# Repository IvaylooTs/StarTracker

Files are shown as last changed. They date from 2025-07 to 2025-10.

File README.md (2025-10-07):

# Repo: Star Tracker

**Team Name:** CASSI  
**Project Name:** CASSI (Celestial Alignment System for Satellite Inertial-control)  
**Official Category:** Star Tracker 1

**Team Members:**  
Michael Yan, Ivaylo Tsekov, Alexandra Nedela, Dilyana Vasileva, Tsvetomir Staykov

## Note: for full and final documentation please read Star_Tracker_3.pdf
---

## Problem

How do we determine our attitude in space?

---

## Project Overview and End Goal

This project implements a star tracking system using a **Raspberry Pi** with an **AI camera** to determine the orientation of the system based on captured star images using a deterministic algorithm. Once calibrated, the system works in tandem with an IMU (Inertial Measurement Unit) to track orientation without continuous visual input. When drifting occurs, due to environmental variables, power loss, or other factors, the system automatically recalibrates.

---

## Current Available Demo

Go to the `digital_twin` folder in the `src` directory. It contains:

- `main.py` – main file with all the systems  
- `star_distances_sorted.db` – database with calculated angular distances, sorted in ascending order  
- `star_identified.png` – sample image from previous tests  
- `test_images` – dir with images from *Stellarium* for testing purposes (uses specific resolution and FOV)
- `create_hash.py` - a script to generate a hash map from database table "AngularDistances"
- `catalog_hash.py` - an already generated hash with the script above using 2 degree tolerance
- `stellarium360_new.js` - a script to be pasted into stellarium console for testing purposes
- `script_images` - dir with images generated from the above script

To run the script, you will need the `sqlite3` and `cv2` libraries installed on your system, and Python 3.

To run the script, use:
```bash
python3 main.py 
```

The results in your terminal should be:

- Indicator of which image you are currently processing
- Which mode you're in (Lost-in-Space / Tracking)
- The resulting quaternion from either of the two modes if one is produced
- The mapping of image star to HIP ID if one is produced

Files that should be generated when you run the script:

- For each image that you're processing you should get a file generated in this format "stars_identified_[index]"

---

## System Architecture

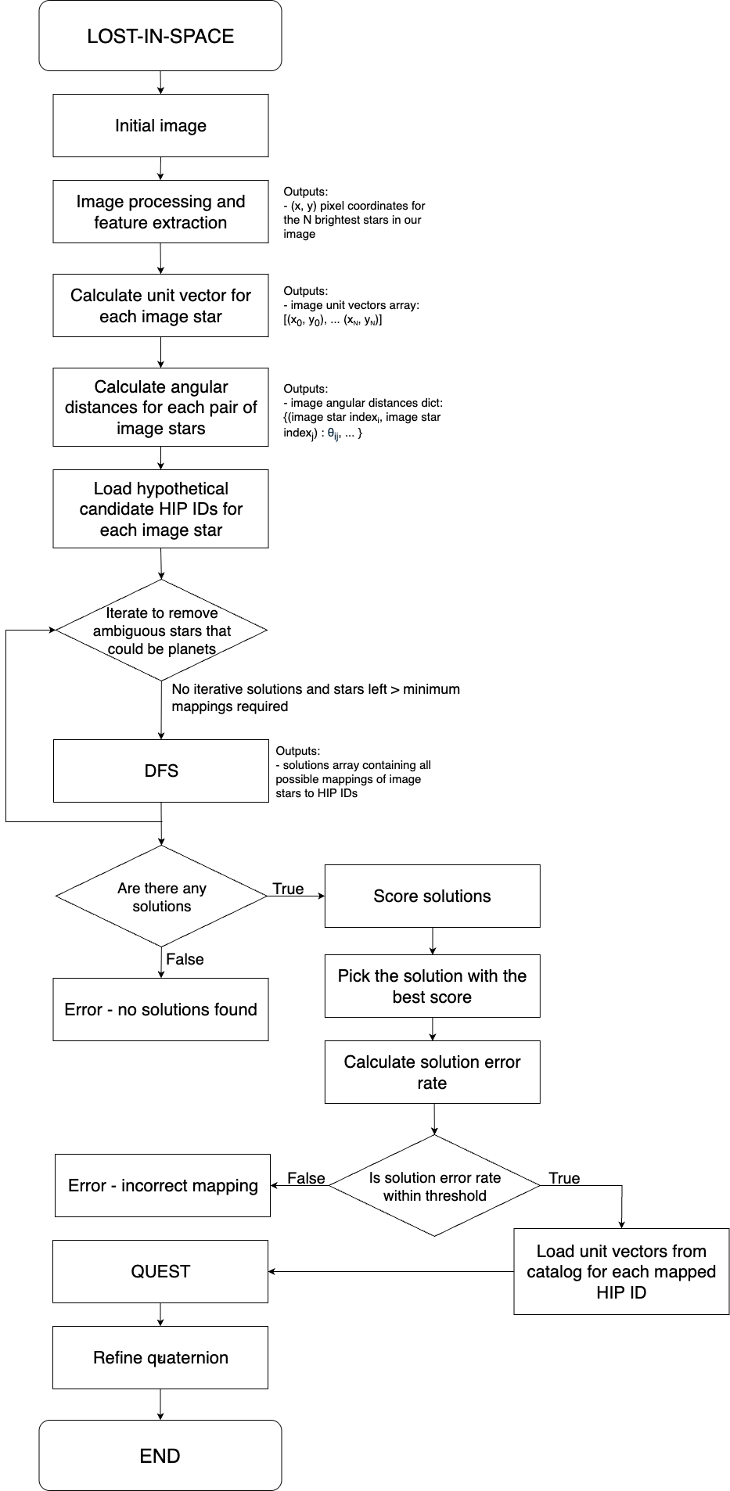
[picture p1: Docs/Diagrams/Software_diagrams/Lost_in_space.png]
Lost-in-Space algorithm Diagram


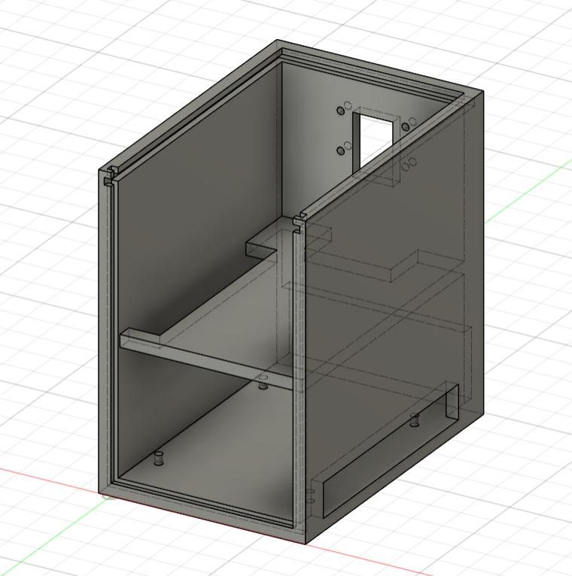
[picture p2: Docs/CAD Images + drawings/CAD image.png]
Cad Design


### Software

#### Database Structure

We have two tables in our database.  
**Table 1 – "Stars"** contains the HIP of each star according to the Hipparcos catalog, the magnitude of each star, and x, y, z coordinates of a unit vector corresponding to their RA and DEC coordinates in the equatorial coordinate system.  
**Table 2 – "AngularDistances"** contains the calculated angular distance between each pair of stars in Table 1, sorted from lowest to highest value.

The stars are filtered based on:

- Brightness  
- Size  
- Eccentricity

#### Lost-in-Space Algorithm

We're implementing a Lost-in-Space approach based on pair matching. The algorithm has four main parts:  
1. Image Processing and Feature Extraction  
2. Angular Distance Calculations  
3. Mapping to Catalog  
4. Attitude Determination

---

#### 1. Image Processing and Feature Extraction

The stars in the image are filtered based on: Brightness, Size, and Eccentricity.  
Then we select the N brightest stars in our image using blob detection and the `cv2` Python module. From this, we get the (x, y) coordinates of the center of each star in the image.

---

#### 2. Angular Distance Calculations

- We center the (x, y) coordinates of the stars based on our image's center, then convert them into vectors with the focal length as the coordinate along the z-axis  
- Convert them into unit vectors to reduce unnecessary computation  
- Calculate the angular distance between each pair (using the cosine of the dot product of the two vectors)

---

#### 3. Mapping Stars to Catalog 

- For each pair of stars in our image, we get the candidates ID pairs from our catalog hash
- Then we assign the candidate IDs for each image star based on a voting system
- Afterwards we run a DFS on this graph-like structure to find all possible mappings (even if incomplete)
- In the end we score the solutions we got from the DFS to get the best one

---

#### 4. Attitude Determination 

- From the final mapping of each star to a certain HIP in our database (from step above), we can now retrieve unit vectors from **Table 1**  
- We build the attitude profile matrix from the two sets of image and catalog vectors
- We then build the attitude profile matrix in quaternion form 
- We solve for the eigenvector with the largest eigenvalue which corresponds to our orientation quaternion

---

#### Tracking algorithm

- For tracking we use a previous orientation quaternion to predict where the stars in our previous image are going to be in the next one 
based on a certain amount of euclidian distance threshold this way we can make small and fast corrections to. We use the hungarian algorithm

---

### Hardware

#### Hardware Integration

- The initial orientation determined via camera is stored as a reference  
- The IMU is zeroed at this orientation  
- Subsequent orientation tracking is performed using only the IMU until recalibration is required due to drift

Notes and Ideas:
- A simple way to recalibrate would be to do it periodically  
- For improved accuracy, consider using Kalman filtering

---

#### Mechanical Design

- Modular, layered physical design:
  - Raspberry Pi  
  - IMU module  
  - Camera mounted perpendicular to the Raspberry Pi board  

- 3D CAD models and assembly diagrams are available in the `DOCS/` directory

---

##  Current Progress

### Software

- [x] Define project requirements  
- [x] Find algorithm for identification of stars  
- [x] OpenCV star identification on image  
  - [x] Test model with math on hand  
- [x] Get angular distances between stars  
- [x] Create database of parameters for comparison (star 1 HIP, star 2 HIP, angular distance)  
- [x] Select candidates for possible stars in specific locations  
- [x] Identify the correct stars  
- [x] Orientation in quaternion form
- [x] Testing  

### Hardware

- [x] Configure Raspberry Pi  
- [x] Connect required modules  
  - [x] Camera  
  - [x] IMU (Gyroscope, Accelerometer, Magnetometer)  
- [x] Calibrate IMU at hardware level  
  - [x] Measure drift  
  - [x] Research drift correction  
- [x] Calibrate IMU at software level  
- [x] Add interface for communication with Arduino (I2C is a good candidate)  
- [x] Develop firmware  
  - [x] Auto boot configuration  

### CAD

- [x] Construct simple box for fit testing and basic implementation  
- [x] Build a better box for testing and protection  
- [x] Satellite enclosure with removable modules  
  - [x] Bottom panel  
  - [x] Sliders  
  - [x] Test sliders  
  - [x] Side protection panels  
  - [x] CASSI module  

### Additional

- [x] Testing | Make black box for testing using images on a monitor  
- [x] Visualization | Make control panel  
  - [x] 3D visualization  
  - [x] Live video  
  - [x] OpenCV calculations  
  - [x] Control buttons  
- [x] Check if static IP is needed (just in case)  
- [x] Study commercial star tracker manuals  
- [x] Consider handling edge cases such as solar flares, moonlight, sun/earth stray light, etc.

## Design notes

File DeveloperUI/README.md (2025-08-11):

# Cassi Developer Interface

Control different aspects of the Cassi system. Visualize data and check if everything is correct.

#### Current windows:
 - 3D visualization of the quaternions
  - toggleable vectors and objects
 - graph for checking for errors in quaternions.
 - buttons with macro commands for fast execution on important commands - lost in space, calibrate, add offset, compare offsets, shutdown, reboot
 - console for CLI interface and live data transfer
 - camera overview
 - simple display information - current quaternion, temp, ram, cpu usage

#### How to run:
Activate `python3 start.py` to boot into server. Originally we wanted to not use server, but due to Cross-Origin Request problems, simplest solution was to boot python server.

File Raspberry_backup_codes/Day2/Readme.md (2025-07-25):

## Day 2 

- Camera connection
- Live video display

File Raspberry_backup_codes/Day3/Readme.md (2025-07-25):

# Day 3

- IMU connection
- Display data in server

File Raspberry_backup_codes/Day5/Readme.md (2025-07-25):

## Day 5

- Calibration with magnetic recalibration stopped
- Recalibration via file on activation

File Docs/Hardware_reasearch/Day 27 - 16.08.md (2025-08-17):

- Make architecture for raspberry pi to change modes
- Make final draft of the documents for hardware and firmware
- make graphs
- study (optinal)

- add button for ui to open image in full screen

We did testing and Ivo made the wrap of lost in space to run many tests on his machine. 
I thought there were problems with the quaternions, but just problem on my laptop visualization was broken, on Ivo's computer it worked without any problems, providing amazing images. Then he coded error determination based on Michael's instructions and we got amazing view of the statistics and tracked average time for 155 images.

Currently Ivo is running around 150 images with different star counts (from 10 to 30), to find the best values for the system. We tried multi-threading, but found problems with the resources being unevenly divided and this show problems with the timing process. Better approach will be, sum operations or single threaded operation for accurate run, then compare the results.

We designed few other tables for the documentation and expanded the hardware and software architecture.

We designed the test with crosses on the screen to align the camera more correctly and get better results. This provided faster calibration on top of the stand.

Tests from Ivo's:
![[Figure_1(1).png]]

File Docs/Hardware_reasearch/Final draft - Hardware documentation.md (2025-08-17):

### Introduction
Introduction to terminology:
- Main board - Small computer, in our case Raspberry PI 4, 4Gb
- IMU - Inertial Measurement Unit, in our case Bosch BNO055
- Camera - in our case SONY IMX500

The hardware system of the star tracker is designed for headless operation in setups:
 - satellite integrated - no outside interfaces, just two-directional communication to another subsystem. 
 - workstation development environment - connected to WiFi, allowing access to development interface, data visualizations and command line interfaces (via the developer interface or secure shell).

If more information is required, please check out the [BNO055 datasheet](https://cdn-shop.adafruit.com/datasheets/BST_BNO055_DS000_12.pdf) by Bosch.
Sadly we couldn't obtain access to the [IMX500 datasheet](https://developer.sony.com/imx500/developer-tools/specifications/reference-and-specifications-archive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) by Sony. For more information contact them.
#### Hardware Specifications and main components List
The system is comprised of 3 main components. Camera, IMU and small main board computer.
##### Camera
- based on Sony IMX500 Intelligent Vision Sensor
	- Why is good: Big pixel count, fast operation and small form factor.
	- Problems: Big field of view, Manual focus (not motorized) 

| Specification | Details |
| --- | --- |
| Sensor | Sony IMX500 |
| Resolution | 12.3 megapixels |
| Sensor size | 7.857 mm (type 1/2.3) |
| Pixel size | 1.55 μm × 1.55 μm |
| Horizontal/vertical | 4056 × 3040 pixels |
| IR cut filter | Integrated |
| Autofocus system | Manual adjustable focus |
| Focus range | 20 cm – ∞ |
| Focal length | 4.74 mm |
| Horizontal field of view | 66.3 ±3 degrees |
| Vertical field of view | 52.3 ±3 degrees |
| Focal ratio (F-stop) | F1.79 |
| Infrared sensitive | No |
| Output | Image (Bayer RAW10), ISP output (YUV/RGB), ROI, metadata |
| Dimensions | 25 × 24 × 11.9 mm |
| Cable connector | 15 × 1 mm FPC or 22 × 0.5 mm FPC |
| Rated operating temperature | 0°C to 50°C |
##### IMU 
- based on BOSCH BNO055 Sensor. 
	- Why is good: Fast operation, simple interface, 9 axis, accurate.
	- Problems: closed algorithms

###### General

| Feature | Details |
| --- | --- |
| Outputs | Quaternion, Euler angles, Rotation vector, Linear acceleration, Gravity, Heading |
| Sensors | 16-bit triaxial gyroscope, 14-bit triaxial accelerometer, full-performance geomagnetic sensor |
| Package | LGA, 28 pins; Footprint: 3.8 × 5.2 mm²; Height: 1.13 mm² |
| Power Management | Intelligent Power Management: normal, low power, suspend modes |
| Voltage Supply | VDD: 2.4–3.6V; VDDIO: 1.7–3.6V |
| Digital Interface | I²C, UART |
| Compliance | MSL1, RoHS compliant, halogen-free |
| Operating Temperature | -40°C … +85°C |
###### Accelerometer

| Feature | Details |
| --- | --- |
| Acceleration Ranges | ±2g, ±4g, ±8g, ±16g |
| Low-Pass Filter Bandwidth | 1kHz – <8Hz |
| Operation Modes | Normal, Suspend, Low power, Standby, Deep suspend |
| On-chip Interrupts | Any-motion (slope), slow/no motion recognition, high-g detection |
###### Gyroscope

| Feature | Details |
| --- | --- |
| Ranges | ±125°/s – ±2000°/s |
| Low-Pass Filter Bandwidth | 523Hz – 12Hz |
| Operation Modes | Normal, Fast power up, Deep suspend, Suspend, Advanced power save |
| On-chip Interrupts | Any-motion (slope), high rate |
###### Magnetometer

| Feature | Details |
| --- | --- |
| Magnetic Field Range | ±1300μT (x-, y-axis), ±2500μT (z-axis) |
| Magnetic Field Resolution | ~0.3μT |
| Operating Modes | Low power, Regular, Enhanced regular, High Accuracy |
| Power Modes | Normal, Sleep, Suspend, Force |
###### Main board
- Raspberry PI 4
	- Why is good: Enough computational power, low energy consumption, many interfaces, many libraries and different ways to integrate.
	- Problems: Closed firmware. Too many unused features.
	
| Feature | Specification |
| --- | --- |
| Processor | Broadcom BCM2711, quad-core Cortex-A72 (ARM v8) 64-bit SoC @ 1.8GHz |
| Memory | 4GB LPDDR4 with on-die ECC |
| Connectivity | • 2.4 GHz and 5.0 GHz IEEE 802.11b/g/n/ac wireless LAN<br>• Bluetooth 5.0, BLE<br>• Gigabit Ethernet<br>• 2 × USB 3.0 ports<br>• 2 × USB 2.0 ports |
| GPIO | Standard 40-pin GPIO header (fully backwards-compatible with previous boards) |
| Video & Sound | • 2 × micro HDMI ports (up to 4Kp60 supported)<br>• 2-lane MIPI DSI display port<br>• 2-lane MIPI CSI camera port<br>• 4-pole stereo audio and composite video port |
| Multimedia | H.265 (4Kp60 decode); H.264 (1080p60 decode, 1080p30 encode); OpenGL ES 3.0 graphics |
| SD Card Support | Micro SD card slot for loading operating system and data storage |
| Input Power | • 5V DC via USB-C connector (minimum 3A)<br>• 5V DC via GPIO header (minimum 3A)<br>• Power over Ethernet (PoE)–enabled (requires separate PoE HAT) |
| Environment | Operating temperature: 0–50ºC |
| MTBF | Ground Benign: 211,000 hours |

#### Environmental Specifications

#### Connectors / Pinouts

The product has Female Header (0.1-inch / 2.54 mm pitch) for connection with other subsystems and giving power to the device. The communication pins allow full-duplex UART communication . The power pins allow to power the device with +5 volts direct current.

![[Pasted image 20250815011902.png]]
Even though the main computer of the system has many connections, only few of them are used.

| Pin name | alternative name | pin number | Used for |
| --- | --- | --- | --- |
| 3v3 | | 1 | powering the IMU |
| GPIO2 | I2C SDA | 3 | IMU data communication  |
| GPIO3 | I2C SCL | 5 | IMU clock sync |
| GPIO14 | UART TX | 8 | Subsystem UART transmit |
| GPIO15 | UART RX | 10 | Subsystem UART receive  |
| GND | | 9 | gounding to IMU |

The Camera is connected directly to the Camera Serial Interface connector, via flat ribbon cable.

![[New Project(2).png]]

The current version uses perfboard (Stripboard or Veroboard) with connections on the bottom (similar to raspberry pi hats), allowing for easy assembly and better connection.

 [picture here]

### Power consumption
#### 

#### Interface Descriptions
- The IMU communicated with the main board via Inter-Integrated Circuit (I2C) communication, which allows for simple 2 wire interface.
- The camera communicated via MIPI (Mobile Industry Processor Interface) Camera Serial Interface standard, which allows high-bandwidth and low-latency data transfer.
- Other subsystems communicated via Full-duplex UART communication, which allows two directions communication at the same time. This interface can be expanded with the cubesat space protocl, like [libscp](https://github.com/libcsp/libcsp). 
  
  ==**!!! Important !!!** The communication protocol uses 3.3 volts due to requirements of the board and the specifications of the General Purpose Input/Output pins, even though the board is powered from 5 volts.
  
- Wifi is used to communicate with the developer interface and the secure shell protocol. This allows for updates, setup of the system and changes in the source code.
#### Firmware

###### Operating system
The operating system of the device is minimalist version of Linux Debian, made specifically for raspberry pi - **Raspberry Pi OS Lite 32-bit**. It runs in **headless** mode with minimal software and drivers, it provides good embedded environment for experimentation with simple integration and possibility for expansion.

| Specification | Data |
| --- | --- |
| Operating system version | Debian version 12 (Bookworm) |
| Firmware version | 24.10.0 |
| Operating system bit | 32-bits |
| Size | 493 MB |
| Kernel version | 6.12 |
###### System architecture
The code is written on python with many modules design for specific purpose:
- main - Combines all modules, runs specific parts in threads, cleans up after execution
- logger - Saves logs, displays information, displays logo, headers, organized output
- math - Computations and arithmetic functions
- flask_server - https server for live video feed and picture download (used for developer interface)
- web_sockets - tcp connection for command and live information transfer (used for developer interface)
- lost_in_space - main algorithms for calculating the attitude based on camera information.
- image_processing - support algorithms for lost_in_space. Identifying stars, etc.
- database and hashmap - all needed values for computation of the algorithms

###### External Device Compatibility
We need to consider that the connection with other subsystems require additional the voltage to be around 3.3 volts. The reason is the operational voltage of the main computer in the device. If you want to operate outside the scope of this, you risk to damage the internal computer.
###### Boot cycle efficiency and optimizations
specific settings were set into place to ensure faster load time of the system.
This are the current settings of the `/tmp/firmware/config.txt`:
```bash
disable_splash=1
boot_delay=0
initial_turbo=30
dtparam=audio=off
dtparam=spi=off
display_auto_detect=0
```

There is problem, where the allocation of less than 32 Mb of memory for the graphical processing unit, don't allow the camera to initialize correctly.   
```
gpu_mem=16
```
For now we will leave it at default value of 128 Mb to ensure stability.
This didn't impact the boot time.

the most improvement in boot speed came from
```bash
sudo systemctl disable NetworkManager-wait-online.service 
```
This cut the boot time with 50%. 

other services were removed to make the device faster and remove unnecessary scripts and programs running in the background
```
bluetooth
hciuart
avahi-daemon
triggerhappy
rpi-eeprom-update 
keyboard-setup
```
Attempts to optimize the SD card, where the whole firmware was stored, were unsuccessful
```
(example)
dtparam=sd_overclock=100 - didn't work, not used
```
after this optimizations we only got down with just 8% 

At the end, we got from around 11 seconds boot time to 5.5 seconds. Which is in the range of most cubesats boot time - around 10-60 seconds.
The shutdown time is around 3-4 seconds, which grants us around 15 second reboot time (some delays present) for the operating system.

The IMU has start-up time from off to configuration mode in 400 milliseconds typical time. and from reset to normal mode in 650 milliseconds mode.
###### System boot sequence
![[BootCycle.drawio(2).png]]

After the system boots, linux service is started. The service is designed to reboot in case of crash of the program it represents - in this case a bash script that reloads the main program.
The bash script is used to ensure that the main program can reboot and call different exit conditions from the developers. The service is to allow overview of the process and to ensure initialization of the boot script and its recovery.

The main program kills every thread that uses port 5000 and 6789, to free slots for Flask server and Websocket. Then the main program runs. There are few cases to consider:
- Exit code 2 - reboots the whole system
- Exit code 3 - shutdowns the whole system
- Any other exit code - reboot program. We use 23 to represent reboot called from the developer interface.
- Crash of main program - reboot program
- Crash of bash boot script - Service reloads

#### Logger
Small script is used to record data with custom commands. We save everything in `logs/` folder, where each file is timestamped.  Custom commands are made for displaying information in the terminal and the file.
Format is "Time | Message type | Information"
Message types are:
- Info
- Success
- Warning
- Error
- Fatal error

## operation
flow charts
systems
architecture
data handling
whatever there is

###### Power consumption

The main board on the system is rated for direct current from power supply, which can deliver 3 amps at 5 volts. The documentation of the device rates typical bare-board active current consumption at 600 milliamps. The GPIO pins can deliver 3.3v at max 16 milliamps current.

| step/process | Amps drawn (A) |
| --- | --- |
| Booting - max | 0.85 |
| Booting - avg. | 0.7 |
| Booting - min | 0.6 |
| Stress -  max | 1.25 |
| Stress - average | 1.2 |
| Halt current (shutdown state) | 0.023 |

Note: These measurements used a standard Raspberry Pi OS image (current as of 26 Feb 2016, or June 2019 for the Raspberry Pi 4), at room temperature, with the Raspberry Pi connected to a HDMI monitor, USB keyboard, and USB mouse, connected to Ethernet. Power consumption can easily exceed these measurements if multiple additional USB devices or a HAT are connected to the Raspberry Pi.

The IMU runs from 2.4V to 3.6V. Total supply current in normal mode with 9 degrees of freedom at 100 Hz output data rate is 12.3 milliamps. The IMU can run in few modes that can save power ( like "Low power" ). We currently only work with normal operation with stopped fast calibration of the magnetometer. 

Possible upgrades:
- Possible extensions on the system to detect current drop below 4.63V (±5%) can be added in the future.

#### Single event upsets (SEU)
In **Low Earth Orbit (LEO)**: SEFIs are expected about **once every ~100 days** per Pi (worst case). Actual rates may be 2–3× lower. 
There is no built-in hardware mitigation. Because Raspberry PIs are designed for commercial on ground off-the-shelf deployment. They don't have any hardware integrations for error-correcting memory or hardened logic. This single event upsets can flip specific sectors, break calculations or even crash the system. There is no **Error-Correcting Code (ECC)** memory on the chip. 

Possible problem can be:
- **bit errors:** crashes, corrupted variables, loops running out of bounds. 
- **Single event function interupts:** Linux kernel panics, system lockups, or garbage communication output. 
- **Permanent failures:** rare but possible from latchups or SD card corruption

Some software implementations can be introduced on the system, but they are not as reliable as hardware that is specifically space-graded. For this version we use most of the default configuration of the operating system, so many things like watch dogs are not activated.

Possible upgrades:
- Install protection mechanisms:
	- Automatic power-cycling if error is detected
	- Change SD card with more redundant/space-graded technology
	- External ECC memory modules
	- filesystems like **Btrfs** or **ZFS** to detect corruption and/or other application level checksum
	- hardware watchdogs timers (Raspberry pi have software watch dogs, but separate modules are mandatory for secure operation)
	- Structural shielding from particles

### IMU Settings
We run the IMU in **NDOF_FMC_OFF** to stop recalibration after booting and loosing general direction. This allows us to not lose direction in case of rebooting the software ran on the star tracker. We stopped the heading calibration and load custom calibration from file. The system is designed for LEO missions, so the magnetometer can be used for calibration of the system. Here few design choices come into play when deciding if magnetometer recalibration on boot is required. In our case we choose to not do it and allow the lost in space algorithm to run the recalibration. This can be changed in future versions or depending on customer requirements.

The IMU settings allow for change in the axis mapping. This is done with a register *AXIS_MAP_CONFIG* and can help when the IMU is not places directly toward the camera. After that we do 45 degree offset to align it with the camera, software wise.

In our NDOF_FMC_OFF mode we allow for the outputs rates of:

| Accel  | Mag | Gyro | Fusion data |
| --- | ----- | --- | --- |
| 100 Hz | 20 Hz | 100 Hz | 100 Hz |

When booting in normal operation mode, by default we load this standard configuration mode

| Sensor | Parameter | Value |
| --- | --- | --- |
| Accelerometer | Power Mode | NORMAL |
| | Range | ±4g |
| | Bandwidth | 62.5 Hz |
| | Resolution | 14 bits |
| Gyroscope | Power Mode | NORMAL |
| | Range | 2000 °/s |
| | Bandwidth | 32 Hz |
| | Resolution | 16 bits |
| Magnetometer  | Power Mode | FORCED |
| | ODR | 20 Hz |
| | XY Repetition | 15 |
| | Z Repetition | 16 |
| | Resolution x/y/z | 13/13/15 bits |
Some of this values are not controllable directly from the developer, but are changed based on the fusion mode used in the chip.

### ** Installation & Setup**
==Most of this should be expanded, because in current state we haven't prepared shipping and packaging. Current development may change the form factor. This is general overview for future documentation== 
#### Unboxing Instructions
The packaging materials are not ready, but this is the planed system:

Open the box you received. Remove the top packing material. Carefully take the Star tracker out of the box. In the box you will also find additional manuals, wires, connector, adapters, testing stand, spare bolts, cleaning materials, stickers, etc..
No special protection or equipment is needed if you want to use it in desk mode, to learn and experiment. 

##### Protective covers
The star tracker relies on camera that need to be clean and ready to take picture at any time. For this reason the device comes with protective cap on top of the camera. Its purpose is to stop dust, humidity or any outside particles and environment variables to interact and lower the efficiency of the star tracker. Remove this cap for testing and before flight. Remember to clean the camera with the provided cleaning materials and/or according to the instructions.

**Cleaning the Star Tracker**

1. **Power Off:** Make sure the device is turned off and unplugged from all power sources.
2. **Dust Removal:** Use a can of clean, dry compressed air to blow away any dust from the lens, connectors, and vents. Hold the can upright and spray in short bursts to avoid condensation.
3. **Lens Cleaning:**
    - If there are smudges on the lens, use a lens cleaning pen or a microfiber cloth made for camera optics.
    - Do not press hard — wipe gently in a circular motion.
    - If needed, add a drop of optical lens cleaning solution to the cloth (never directly on the lens).
4. **Body Cleaning:** Wipe the housing with a soft, dry cloth. Slightly damp cloths are fine for stubborn marks. Never let liquid enter any opening. 

**Protective Covers**
- **Lens Cap:** Always put the supplied lens cap on when the Star Tracker is not in use. This prevents dust, scratches, and accidental fingerprints.
- **Connector Covers:** If your model includes rubber or plastic covers for USB-C, UART, or power connectors, place them after each use to keep out dust and debris.
- **Transport Case:** For storage or transport, place the Star Tracker back into its original foam-lined box or into a padded protective case to protect against shock and vibration.
**Important:**
- Never use household cleaning sprays, alcohol, or abrasive materials on the lens or housing.
- Avoid storing the unit in direct sunlight, humid areas, or near strong magnetic/electrical fields.
#### Physical Installation / Mounting Instructions
The star tracker is design to install in CubeSat with sizes of 1U to 3U, or any system that can support the design [please expands]. The system also can be installed on desk or workstation, connected via usb-c for power.
All bolts in the design are m2 screws with specific length and star head end, coutner sunk or some shit, idk, Michael your turn
#### Electrical Connections
The raspberry pi can be connected via usb-c for desk/workstation operation 
When you need to install the system in the satellite, connect the UART and power pins based on the provided diagram.

##### Initial Power-Up Procedure
Power the device with the power requirements described in section [somewhere]

Before powering the device make sure all connection are secure and there is no visible damage on the device. Ensure Ethernet cable is connected so that you can connect to via secure shell or the developer interface and control the software. 
When the device received power, the booting process starts.
On first boot it enters into standard desk operation. In this way you can connect to it and change the system parameters.

Future upgrades:
- make pin for selecting the operational based if it connected to ground or not

##### Configuration and Calibration
The device comes with small white circle with small pins to calibrate the focus of the camera. The current setup requires to use external monitor for testing (16:9 aspect ration), positioning the camera module to be able to capture the whole monitor. After positioning you can rotate the camera lens, by positioning the calibration tool on top of the camera lens, by aligning the hole in the middle. Look at the developer software to see the change of focus. In this way you can find the optimal focus length for your test bench. The provided stand is for 23 inch monitor with 16:9 aspect ratio.
You can test the functionality from the command line interface or the buttons provided. The secure shell connection doesn't allow for command to be send when we are in ssh session with booted and displayed Star Tracker Software. In that case you control the system via the Developer interface. The ssh is used for direct control and access of the source code.

Future upgrades:
- Stand with ability to manually change position, based on the size of screen.
- Better secure shell CLI interfacing for direct control without the GUI.
### **Maintenance & Troubleshooting**
- Routine Maintenance Guidelines
- Troubleshooting Guide (symptoms → causes → fixes)
### Firmware Update Procedure
if you want to update the firmware you can download and flash an iso by contacting customer support from the link on our website or download the source code from Github and install it manually on the device via the scp.
https://github.com/IvaylooTs/StarTracker
Note: Save your settings by exporting them manually. You can easily override them and lose valuable configuration settings. 

Future upgrade:
- Simple export and import for settings via the developer interface and ssh
#### Replacement Parts / Consumables
The raspberry pi 4Gb, sd card, AI camera and IMU can be found from many distributors and this makes the current version of the system - accessible and easily reparable. For the pcb design, structure or any other part, contact us via our customer email or our website.   

## Developer Interface
The developer interface is designed specifically to run on computer, connected on the same network as the main computer. It provides overview and visualization of the most important information. It is programmed with html, css and javascript like a normal website. Libraries used are Three.js for 3d visual visualization and Graph.js for quaternion data visualization in graphs

It connects via websocket on port 6789 to transmit data in two directional. The data is transfer in json format. The main board sends constantly data about its quaternion rotation, temperature, cpu and ram loads. Any other information is manually requested with command in the command line interface (or just console) inside the developer interface. Few command can be send via buttons for faster call:
- save and download current video feed image as picture on the user computer
- activate test with image on board
- activate lost in space with camera view
- add custom quaternion value
- calibrate IMU to last calibration
On the left of the terminal is present live data feed and on the right are last command and acknowledgements made from the raspberry pi and the system.
If connection is lost or not made, websocket tries to reconnect. Some problem are recorded that it can take some time to establish connection. It can range between instant connection to 10-15 seconds wait. Refreshing the interface, rebooting the software or cleaning the cached page data seem to help for now. (this will be fixed in future developments)

Flask server is loaded with live feed from the camera. It can be accessed on port 5000 from any browser in with URL "https://{ip}:5000/video_feed". It is also displayed in small window in the developer interface. We use https, because of cross site resource management and display. The problem occurs, because the video feed is hosted on the raspberry pi and the visualization happens on our web interface on another computer. We use locally generated certifications and we need to connect to the link above to accept "the risks" with connecting to this system.

Note: The Websocket and Flask server are not active in Satellite mode.

Initial concept design:
![[ConceptUI.drawio.png]]

Current version:
![[Pasted image 20250816112906.png]]

Most of the things are the same as the concept. We can see that the the graph and system data visualization are switched. on the panel on the right you can scroll down to see more control buttons for testing (in controls panel), and system stats (in the visualized data).

Console visualized:
![[Pasted image 20250816113234.png]]

Camera window:
![[Pasted image 20250816113339.png]]

Visualization toggle:
![[Pasted image 20250816113548.png]]

Note: The star visualization on the 3D visualization is only visible when the python script 'start.py' is started and we are connected to the local ip. We cannot load the image the image because of some html problems and resource management.

Future upgrades:
- more control buttons
- better visualization
- movable windwos
- more graphs and information

### On board CLI
When you boot into the raspberry pi and run the script manually, you see this visualization 
![[Pasted image 20250816114728.png]]
![[Pasted image 20250816114743.png]]![[Pasted image 20250816114829.png]]
This helps you display debugging information

The problem is that you cannot write CLI commands while you are in this interface.
For future development we can add this function.

### **Testing & Validation of hardware**

- Factory Test Procedures
- Quality Control Checklist
- Environmental Stress Tests
- Electrical and Functional Testing
### **Diagrams & Schematics**

- Block Diagrams
- Circuit Schematics

- PCB Layouts

- Wiring Diagrams

## Developer interface

### **Appendices**

- Glossary of Terms
- Reference Documents / Standards
- Revision History / Changelog
- Contact Information / Support

https://randomnerdtutorials.com/raspberry-pi-pinout-gpios/

https://www.raspberrypi.com/documentation/computers/raspberry-pi.html#power-supply
https://nepp.nasa.gov/docs/papers/2021-Guertin-Raspberry-Pi-Guideline-CL-21-5641.pdf

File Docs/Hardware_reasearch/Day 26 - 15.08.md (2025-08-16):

- System architecture for boot and picture capture
- UART comms
- softwar

Build Sat/Desk mode change, Decided on architecture for downloading data
![[Pasted image 20250816101217.png]]

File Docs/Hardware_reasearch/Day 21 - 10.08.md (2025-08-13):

- [ ] Fix the UI 
	- [x] Quaternions
		- [x] Add a way to toggle the displayed values
		- [x] Angles difference
	- [ ] Additional
		- [ ] Fix the button sizes
		- [ ] Connect the reboot and shutdown button
- [x] Check the quaternions from the calibration
	- [x] Check if rotation is fine in pitch and yaw
	- [ ] Check the Roll
- [ ] Integrated precise measurements
	- [x] Check if Didi's code is actually working with low tolerance
	- [x] Check if my code works on Didi's resolution
- [x] Integrate the box
	- [x] Tell Michael to build a test rig holder
- [ ] Fix the integration interface
	- [ ] Add base interface for command calls
- [x] Study for the test
	- [x] Lectures
		- [x] Remote sensing
		- [x] 3D mechanical design
		- [x] Git
- [ ] if enough time
	- [ ] movable windows for camera

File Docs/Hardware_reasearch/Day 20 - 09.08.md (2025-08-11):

- [ ] Fix the UI 
	- [x] CLI comms
		- [x] Integrate the CLI inside the browser
		- [x] Seperate the data into Data-link and Commands
		- [x] Fix the acknowledgement for the CLI interface
	- [ ] Quaternions
		- [x] Do a better visualization of the calibrated quaternions
		- [ ] Add a way to toggle the displayed values
		- [x] Orbital controls
		- [ ] Angles difference
	- [ ] Additional
		- [ ] Fix the button sizes
		- [ ] Connect the reboot and shutdown button
- [ ] Check the quaternions from the calibration
	- [ ] Check if rotation is fine in pitch and yaw
	- [ ] Check the Roll
- [ ] Integrated precise measurements
	- [ ] Check if Didi's code is actually working with low tolerance
	- [ ] Check if my code works on Didi's resolution
- [ ] Integrate the box
	- [ ] Tell Michael to build a test rig holder
- [ ] Fix the integration interface
	- [ ] Add base interface for command calls
- [x] Study for the test
	- [x] Check if there are any videos on spaceport
	- [ ] Lectures
		- [x] How to make a star
		- [x] Quantum
		- [x] To space / through space
		- [x] the urgent need for solutions and the policy
		- [ ] Remote sensing
		- [ ] 3D mechanical design
		- [ ] Git
- [ ] if enough time
	- [ ] movable windows for camera

Added visualization on the UI so the focus is on the 3D view. Made camera and CLI toggleable in the down left corner of the screen. Want to add so you can move the window, but that is not necessary right now Added console inputs so i can send custom commands to the raspberry, even ones that are not in the buttons.
Make the received data into one window and commands in the other. Made functions to write to them separately.

Now I need to add last quaternion calibration. I tried doing it saving it on the html, but decided to move it on the raspberry pi for simpler execution and send the data via command.

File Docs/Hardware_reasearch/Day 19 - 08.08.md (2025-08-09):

after the hike i tried to implement the the "Nuke" solution into the main digital_twin code, sadly no luck. 
Experiments show that the error in the angular distances are the same as the "Nuke" fix for few selected stars. Need to check with Didi for that. 

The uart protocol is implemented by Ivo. We think of 2 interfaces - websocket and uart. They are on top of one singular interface, that has all the commands that the raspberry can implement. 

```python
import numpy as np

# Original quaternions given
q1 = np.array([-0.05475243,  0.00503133,  0.00334414,  0.99848168])
q2 = np.array([0.53389495, -0.26937958, -0.25995519, -0.75816498])

def normalize(q):
    return q / np.linalg.norm(q)

def angle_between_quaternions(q1, q2):
    q1 = normalize(q1)
    q2 = normalize(q2)
    dot = np.abs(np.dot(q1, q2))
    dot = np.clip(dot, -1.0, 1.0)  # Clamp for safe arccos
    angle = 2 * np.arccos(dot)
    return np.degrees(angle)

# 1) (x, y, z, w) ordering
angle_xyzw = angle_between_quaternions(q1, q2)

# 2) (w, x, y, z) ordering: rearrange components
q1_wxyz = np.array([q1[3], q1[0], q1[1], q1[2]])
q2_wxyz = np.array([q2[3], q2[0], q2[1], q2[2]])
angle_wxyz = angle_between_quaternions(q1_wxyz, q2_wxyz)

angle_xyzw, angle_wxyz

```

```javascript
// capella_label_and_coords.js
// Move to Capella, print coordinates, and add a dark-gray label "capela test 1"

// Helper: convert RA in decimal degrees to "HH:MM:SS.s"
function raDegToHMS(raDeg) {
    // RA: 360 deg = 24h -> hours = raDeg / 15
    var totalHours = raDeg / 15.0;
    var H = Math.floor(totalHours);
    var mFrac = (totalHours - H) * 60.0;
    var M = Math.floor(mFrac);
    var s = (mFrac - M) * 60.0;
    // format with fixed seconds to 2 decimals
    return H + ":" + (M < 10 ? "0"+M : M) + ":" + s.toFixed(2);
}

// Helper: convert Dec in decimal degrees to "±DD:MM:SS.s"
function decDegToDMS(decDeg) {
    var sign = decDeg < 0 ? "-" : "+";
    var absDec = Math.abs(decDeg);
    var D = Math.floor(absDec);
    var mFrac = (absDec - D) * 60.0;
    var M = Math.floor(mFrac);
    var s = (mFrac - M) * 60.0;
    return sign + D + ":" + (M < 10 ? "0"+M : M) + ":" + s.toFixed(2);
}

try {
    // 1) Select object and move view to it
    core.selectObjectByName("Capella", true);      // select (pointer on)
    core.moveToObject("Capella", 1.0);             // move view to Capella in 1 second

    // short wait to ensure selection/move are done in the script (adjust if needed)
    core.wait(1.0);

    // 2) Obtain object info map
    var info = core.getObjectInfo("Capella");

    // 3) Safely read RA/Dec (current frame) and J2000 if available
    var raDeg = (typeof info["ra"] !== "undefined") ? info["ra"] : null;
    var decDeg = (typeof info["dec"] !== "undefined") ? info["dec"] : null;
    var raJ2000 = (typeof info["raJ2000"] !== "undefined") ? info["raJ2000"] : null;
    var decJ2000 = (typeof info["decJ2000"] !== "undefined") ? info["decJ2000"] : null;

    // 4) Print full info map for debug / completeness
    core.output("---- Capella: raw info map ----");
    core.output(core.mapToString(info));
    core.output("--------------------------------");

    // 5) Print nicely formatted coordinates
    if (raDeg !== null && decDeg !== null) {
        core.output("Current-frame RA  (deg): " + raDeg.toFixed(6));
        core.output("Current-frame Dec (deg): " + decDeg.toFixed(6));
        core.output("Current-frame RA  (HMS): " + raDegToHMS(raDeg));
        core.output("Current-frame Dec (DMS): " + decDegToDMS(decDeg));
    } else {
        core.output("Current-frame RA/Dec not available in getObjectInfo() result.");
    }

    if (raJ2000 !== null && decJ2000 !== null) {
        core.output("J2000 RA  (deg): " + raJ2000.toFixed(6));
        core.output("J2000 Dec (deg): " + decJ2000.toFixed(6));
        core.output("J2000 RA  (HMS): " + raDegToHMS(raJ2000));
        core.output("J2000 Dec (DMS): " + decDegToDMS(decJ2000));
    } else {
        core.output("J2000 RA/Dec not present in the info map (some Stellarium versions may omit them).");
    }

    // 6) Add a dark-gray label attached to the object.
    // Parameters: text, objectName, visible, fontSize, fontColor, side, labelDistance, style
    // Use a dark gray color like "#444444"
    var labelId = LabelMgr.labelObject("capela test 1", "Capella", true, 14, "#444444", "E", -1.0, "TextOnly");

    if (labelId >= 0) {
        core.output("Label created (id = " + labelId + "). Text: \"capela test 1\" Color: #444444");
    } else {
        core.output("Failed to create label. Ensure the object name 'Capella' is available in English in this Stellarium instance.");
    }

} catch (e) {
    core.output("Script error: " + e.toString());
}

```

```javascript
// polaris_label_and_coords.js
// Removes previous Capella label, moves to Polaris, prints coordinates, adds label "polaris test 1"

// Keep the label ID from previous script if in same Stellarium session
try {
    if (typeof labelId !== "undefined" && labelId >= 0) {
        LabelMgr.deleteLabel(labelId);
        core.output("Removed Capella label (id = " + labelId + ").");
    } else {
        core.output("No previous Capella label found to remove.");
    }
} catch (e) {
    core.output("Error while removing Capella label: " + e.toString());
}

// Helper: convert RA in decimal degrees to "HH:MM:SS.s"
function raDegToHMS(raDeg) {
    var totalHours = raDeg / 15.0;
    var H = Math.floor(totalHours);
    var mFrac = (totalHours - H) * 60.0;
    var M = Math.floor(mFrac);
    var s = (mFrac - M) * 60.0;
    return H + ":" + (M < 10 ? "0"+M : M) + ":" + s.toFixed(2);
}

// Helper: convert Dec in decimal degrees to "±DD:MM:SS.s"
function decDegToDMS(decDeg) {
    var sign = decDeg < 0 ? "-" : "+";
    var absDec = Math.abs(decDeg);
    var D = Math.floor(absDec);
    var mFrac = (absDec - D) * 60.0;
    var M = Math.floor(mFrac);
    var s = (mFrac - M) * 60.0;
    return sign + D + ":" + (M < 10 ? "0"+M : M) + ":" + s.toFixed(2);
}

try {
    // 1) Select object and move view to it
    core.selectObjectByName("Polaris", true);
    core.moveToObject("Polaris", 1.0);

    // short wait
    core.wait(1.0);

    // 2) Obtain object info
    var info = core.getObjectInfo("Polaris");

    var raDeg = (typeof info["ra"] !== "undefined") ? info["ra"] : null;
    var decDeg = (typeof info["dec"] !== "undefined") ? info["dec"] : null;
    var raJ2000 = (typeof info["raJ2000"] !== "undefined") ? info["raJ2000"] : null;
    var decJ2000 = (typeof info["decJ2000"] !== "undefined") ? info["decJ2000"] : null;

    // 3) Print raw info
    core.output("---- Polaris: raw info map ----");
    core.output(core.mapToString(info));
    core.output("--------------------------------");

    // 4) Print nicely formatted coordinates
    if (raDeg !== null && decDeg !== null) {
        core.output("Current-frame RA  (deg): " + raDeg.toFixed(6));
        core.output("Current-frame Dec (deg): " + decDeg.toFixed(6));
        core.output("Current-frame RA  (HMS): " + raDegToHMS(raDeg));
        core.output("Current-frame Dec (DMS): " + decDegToDMS(decDeg));
    } else {
        core.output("Current-frame RA/Dec not available.");
    }

    if (raJ2000 !== null && decJ2000 !== null) {
        core.output("J2000 RA  (deg): " + raJ2000.toFixed(6));
        core.output("J2000 Dec (deg): " + decJ2000.toFixed(6));
        core.output("J2000 RA  (HMS): " + raDegToHMS(raJ2000));
        core.output("J2000 Dec (DMS): " + decDegToDMS(decJ2000));
    } else {
        core.output("J2000 RA/Dec not present.");
    }

    // 5) Add dark gray label for Polaris
    var polarisLabelId = LabelMgr.labelObject("polaris test 1", "Polaris", true, 14, "#444444", "E", -1.0, "TextOnly");

    if (polarisLabelId >= 0) {
        core.output("Label created for Polaris (id = " + polarisLabelId + ").");
    } else {
        core.output("Failed to create Polaris label.");
    }

} catch (e) {
    core.output("Script error: " + e.toString());
}

```

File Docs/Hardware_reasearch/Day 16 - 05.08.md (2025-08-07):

- [ ] Read Raspberry pi camera documentation -> [link](https://datasheets.raspberrypi.com/camera/picamera2-manual.pdf)
- [x] Add register read for errors from the IMU 
- [ ] enter specific modes

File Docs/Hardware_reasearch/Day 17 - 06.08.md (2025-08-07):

- [x]  integration!
- [ ] Find if quaternions are correct
- [x] Run IMU correctly again

Q1 of day - come here, need to continue working on the circuit design, Let Ivo do it for me, while i started integration on the lost in space and get the image from the IMU
Q2 of day - started working on integartion. 1-2 hours of fixing websockets problems, i made the pi take a image from the screen, then read it and check lost i nsapce

After I test it with sample image capture I modified the script to run and save the located stars locally and test the script.

made a small test bench with Ivo's PC and monitor, then integrated the raspberry and run the script. 

After some movement and placement of the raspberry PI we got the correct values for the hips of the stars, checked them and it works.

after that we ran the same test from the same place and it worked again! I cannot believe this! now i wonder what is going to go wrong. We need to do so many tests, be we have only around 13 days left.

### 1. Prepare your data

Make sure you have two matching lists of **unit vectors** (numpy arrays):

```
import numpy as np

# Reference vectors from star database (shape: N x 3)
V = np.array([
    [x1, y1, z1],
    [x2, y2, z2],
    ...
])

# Measured vectors from your sensor (shape: N x 3)
W = np.array([
    [x1', y1', z1'],
    [x2', y2', z2'],
    ...
])

```
### 2. Compute matrix B
```
B = W.T @ V  # shape: (3, 3)

```
### 3. SVD of B

`U, S, Vt = np.linalg.svd(B)`

### 4. Compute rotation matrix
`R = U @ np.diag([1, 1, np.linalg.det(U @ Vt)]) @ Vt`
### ### 5. Use the rotation

Now you can rotate any vector from the reference frame into your sensor frame:
```
v = np.array([x, y, z])  # from database
w_estimated = R @ v      # should match your measurement
```

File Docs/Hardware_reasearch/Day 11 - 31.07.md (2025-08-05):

For this day I want to implement the offset, due to the fact that soon maybe we will have to integrate the digital twin in the system. Also I need to help with the documentation and summery of the data and separating the data into manageable chunks.

###### TODO:
- [x] offset quaternion based on angle test
- [x] Documentation
- [ ] Arduino Communication protocol and read data from PC  
- [ ] Detect bad sensor config and reload systems
---

Found this documents with information on mounting -> https://www.bosch-sensortec.com/media/boschsensortec/downloads/handling_soldering_mounting_instructions/bst-bno055-hs000.pdf

Here is example of something good to consider when mounting the system.
![[Pasted image 20250731134919.png]]

new problem arises
When you spin the sensor very fast it detects a big threshold and glitches.
one way to fix it is by adding queue.
this solution proved to give too much problems with slowing the IMU data transfer for 0.5 seconds (the threshold value)
the next solution just checks for a difference in two parallel reads. Small waits can be seen in graph, but the visualization is still good.
This problem should be fixed with sampling average of chunks of data or faster data sampling.
![[Screenshot From 2025-07-31 18-01-20.png]]

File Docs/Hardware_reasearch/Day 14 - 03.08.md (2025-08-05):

Starting to transferring the whole schematic from breadboard to prototype soldering board.

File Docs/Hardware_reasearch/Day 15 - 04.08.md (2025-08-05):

- [ ] Calibrate Camera
- [ ] First tests in chamber?
- [x] Digital twin integration test
- [ ] Kalman filter
- [x] Auto boot into Software test
- [x] Detect bad boot 
- [ ] clean installation

Decided to transfer the system from breadboard to custom made test board with soldered connection for better conductivity and simpler assembly

[image]

Added the lost in space by Didi and UART communication (which is in thread) from Ivaylo

Added button to connect active lost in space. Integrated the function. This needs to be expanded with threads.

installed ```pip install pyserial``` to main virtual environment

Made checks for missing Camera and IMU modules. basic stuff, need expansion toot display errors

Added better CLI ->
- better text headers with specific ASCII symbols for better design 
- made types of messages
- Added time stamps to commands
- every part of the print is in separated function and in `Flare.py` for usage in the whole system.
I think that we can use `if __name__ == "__main__"` to test each code module on its own.

Made intro animation  for the graphical interface using `Anime.js`

No need to use external quartz crystal, because the IMU has integrated one.

### found to be problem
Arduino gets powered from Raspberry PI 3v3 from TX pins GPIO 14.
Possible solutions may be using resistor or diode.
Tried using resistor with value of 1k ohm, but it still gets powered. May need to replicate the issue on breadboard and see if it is still present.

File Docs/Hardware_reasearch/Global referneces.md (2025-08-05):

### Hardware
##### Raspberry PI 
-  Main board - Raspberry PI 4, 4GB: https://www.raspberrypi.com/products/raspberry-pi-4-model-b/specifications/
- Main board - Mechanical construct: https://datasheets.raspberrypi.com/rpi4/raspberry-pi-4-mechanical-drawing.pdf
- Raspberry PI AI camera datasheet: https://datasheets.raspberrypi.com/camera/ai-camera-product-brief.pdf
- Raspberry PI cameras in general: https://www.raspberrypi.com/documentation/accessories/camera.html (some comparisons)
##### IMU
- Bosch product website: https://www.bosch-sensortec.com/products/smart-sensor-systems/bno055/#applications
- bno055 chip datasheet: https://cdn-shop.adafruit.com/datasheets/BST_BNO055_DS000_12.pdf
- bno055 chip mounting docs: https://www.bosch-sensortec.com/media/boschsensortec/downloads/handling_soldering_mounting_instructions/bst-bno055-hs000.pdf
### Math
- Quaternion explained:https://danceswithcode.net/engineeringnotes/quaternions/quaternions.html  
- Kalman filtering: https://blog.tkjelectronics.dk/2012/09/a-practical-approach-to-kalman-filter-and-how-to-implement-it/
- Kalman filtering in arduino: https://www.instructables.com/Guide-to-gyro-and-accelerometer-with-Arduino-inclu/

#### parts
32khz quartz for IMU: https://elimex.bg/product/48764-kvarts-32-768khz-dt38

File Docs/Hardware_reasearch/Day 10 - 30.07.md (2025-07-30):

12:30 Lecture was canceled 
12:35 Simo said I need to check general stuff for the video capture of the chamber and give him feedback as soon as possible

- [x] Graph the data from the IMU
- [x] Fix the weird jumps in rotation of quaternions
- [x] Backup newest code to github raspberry pi code and website
- [x] Temperature display

### day before
Some important things for data from IMU:
- normalization of quaternions - correct math (not entering the 4d dimention, a.k.a. scaling)
- SLERP - smooth transition between data (no sudden jumps)
- Noise Clamping - if the change is too small ignores it

Possible problems for Noise Clamping - I think, if threshold is too big, small drift can accumulate over time. This needs verification. 

Concept to check for nomralization of quaternion:
```python
import numpy as np
from scipy.spatial.transform import Rotation as R

def normalize_quaternion(q):
    return q / np.linalg.norm(q)

def ensure_hemisphere(q1, q2):
    """Ensure q2 is in the same hemisphere as q1."""
    if np.dot(q1, q2) < 0:
        return -q2
    return q2

def slerp(q1, q2, t):
    """Spherical linear interpolation between q1 and q2."""
    r1 = R.from_quat(q1)
    r2 = R.from_quat(q2)
    return R.slerp(0, 1, [r1, r2])(t).as_quat()

# Example usage
q_prev = normalize_quaternion(np.array([0.0, 0.0, 0.0, 1.0]))  # previous quaternion
q_current = normalize_quaternion(np.array([0.0, 1.0, 0.0, 0.0]))  # current quaternion

q_current = ensure_hemisphere(q_prev, q_current)
q_smoothed = slerp(q_prev, q_current, t=0.5)  # interpolate halfway

print("Smoothed Quaternion:", q_smoothed)

```

---

### Jump filter
Random sudden jumps were fix using this threshold to ignore based on dot product greater than specific threshold. 
- this required high frequency data rate from IMU to main computer 

```python
LastQuaternion =(1, 0, 0, 0) # used for gitter cleanup
def DetectJitter(quaternion, threshold=0.25):
	global LastQuaternion
	if LastQuaternion == (1, 0, 0, 0):
		LastQuaternion = quaternion
		return quaternion
	else:
		diff = math.sqrt((LastQuaternion[0] - quaternion[0])**2 +
		(LastQuaternion[1] - quaternion[1])**2 +
		(LastQuaternion[2] - quaternion[2])**2 +
		(LastQuaternion[3] - quaternion[3])**2)
	if diff > threshold: # threshold for jitter detection
		print("Jitter detected, returning last quaternion. Difference:", diff)
		return LastQuaternion
	else:
		LastQuaternion = quaternion
		return quaternion
```

Quaternion jump/flip detection is easily seen in the graph:
![[Screenshot From 2025-07-30 15-38-25.png]]
The code above fixes this problem, but brings new thing.
Do you have a speed from sensor to recalculate the rotation fast enough? if I rotate the IMU fast enough, will it glitch?
- solution - If more than 5-15 checks are found that the quaternion is out of scope because of jump, it is probably not a glitch, but a fast flip in space and should be reconfigured, probably enter a **Infinite spin warning** to warn the satellite to slow down rotation. (problem found during release)

## software redundancy
In case of system failure of hardware components, there should be custom software implementation to handle the data and continue calculations with damaged systems.

If gyroscopes, Accelerometer, magnetometer or sensor fusion chip breaks, we need backup software to continue the operation of the systems. 

Development of this systems require mathematical functions to neglect error accumulation and configure the system for sensor-damage mode

##### Sensor damage modes:
1. one system damaged
	- Gyroscope - you can use magnetometer to get general direction, but very limited rotation
	- Accelerometer - unprocised gyroscope, lost of general movement and drift accumulation
	- Magnetometer - lost of heading, drift accumulation, Kelman filter fix
	- Sensor fusion chip - best case, continue calculations on raspberry pi, no further notice
2. two system damaged
	- only magnetometer - general idea of direction thanks to magnetometer
	- only accelerometer - maybe possible orientation to relative position, could work with known current rotation, but probably use complex algorithms
	- only gyroscope - could remain in relative rotation, possible big drift problems in just 10-15 seconds
3. three damaged systems
	- .... damn. Basically nothing can do.

- accelerometer to rotation - https://stackoverflow.com/questions/3755059/3d-accelerometer-calculate-the-orientation

##### Boot sequence:
1. Load normal operational mode
2. Check for init error
3. Check for calibration error
4. Check if all system work correct
5. Establish correction mode
	1. No errors - continue in standard mode, no magnetic recalibration 
	2. Errors in sensors - Restart sensors
	3. Continues error - Enter "sensor failure mode"

##### Ideas for error checks
| Address check | Possible error | State |
| --- | --- | --- |
| **Self-test result (0x36)** | Checks BNO055's internal self-test result | Pass/fail per sensor |
| **System status (0x39)** | Detects if system error occurred | 0x01 = error |
| **System error (0x3A)** | Identifies if gyro failed to initialize | 0x06 = gyro failure |
| **Live data checks** | Detects runtime anomalies | Use zero/static/outlier detection |

##### Software reset sudo code
1. mode reset - change the modes and reload 
2. trigger software reset and recalibration in register
```python
BNO055_SYS_TRIGGER = 0x3F
BNO055_OPR_MODE    = 0x3D
CONFIGMODE         =  0x00

# Put BNO055 into config mode first
writeRegister(BNO055_OPR_MODE, CONFIGMODE);
delay(25);

# Issue software reset
writeRegister(BNO055_SYS_TRIGGER, 0x20);
delay(650);  # Wait for reset to complete

# Reinitialize sensor mode/settings here
#  .....
```
(You can poll **`0x00` (CHIP_ID)** after reset—it should read `0xA0`. This helps confirm that the BNO055 is responding again.)
3. Power resistor that can shut down power directly

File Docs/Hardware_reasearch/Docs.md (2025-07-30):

## Sensor Fusion Algorithm Design (e.g., Kalman Filter)

The main sensor fusion functionality is the combination of the Lost-in-space algorithm and IMU (inertial measurement unit) sensor data to calibrate and get accurate attitude data. There is another layer that can be explored to add redundancy in the system in case of hardware failure in specific sensor of the IMU.

for more information of the IMU check **IMU sensor - BNO055**
##### The problem with this external chip
Bosch kept the algorithms and firmware closed source. We cannot directly know what the chips is doing or change the code installed on it. 
#### Other possible solutions
We can still access the data from the sensors from their respective registers and shut off the computation logic. This can be useful in case of failure of the chip, algorithms or specific sensors. We can extract the information and do the computation on the main system and continue with the operation of the module with few limitations.
Right now this is in *research & development* state.

This is imagined to boot and check all needed registers for errors and reboot the sensor one time and then if this still fails, enter "sensor failure" mode, based on what stopped working. If everything is fine, we enter standard mode (without auto magnetic recalibration)
# Firmware 
Firmware is the main code that runs on the hardware and allows the integration of the software. Our system runs on Debian Linux 32-bit in headless mode.

The main program will boot and load needed libraries and subprograms for camera and IMU configuration, sensor fusion, data handling, communication, lost-in-space algorithms and database tables.

This operating system will run with limited system functionality - bluetooth, wifi, ethernet, most drivers and other unnecessary systems will be deactivated or deleted to save on space and efficiency.

It is important to note that Wifi is currently the only way to access the UI interafece and get information on the system. 
The {protocol} is used to allow the main computer to communicate with other subsystems and return quaternion information and receive commands for operation.

The protocols used for information transfers and direct controls are:
- SSH
- Websockets (2-way)
- Flask web server
### IMU sensor - BNO055
The current implementation uses the **bno055** for an IMU with integrated sensor fusion chip and proprietary Bosch algorithms for sensing and error correction in drift and other systems. It combines data from gyroscope, accelerometer and magnetometer, depending on the currently activated mode in the specific hardware register. Thanks to this chip we export the IMU data calculation on another system, so that the main computer (the Raspberry PI) has more free resources for other computation. 

TODO (for Tsetso): add statistics...
### Camera - Raspberry PI AI camera
This is one of the official Raspberry PI camera with 4056 x 3040 pixels (12.3 megapixels) resolution, based on the Sony IMX500. Even though this camera is designed for AI uses, It provides good photo quality and allows for faster and easier implementations. The AI chips allows for future developments and non-deterministic algorithms to be implemented.

TODO (for Tsetso): add statistics...
# Controls
To easily configure and work with the module, we provided a UI interface for control of the system and analysis. It gives easier way to visualize the information, see camera output and test specific functionalities (force calibration, change modes, etc..).
On the current version you can see 6 panels:
- 3D visualization of the quaternion data (using Three.js)
- Graph visualization of the quaternion data (using Graph.js)
- Received information in terminal
- Camera live* view (could be delays in slow computers or busy networks)
- General quaternion and system data
- Control buttons

The video feed is transferred via Flask web server hosted on the module and the data is received via websockets

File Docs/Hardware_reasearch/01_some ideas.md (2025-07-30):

- [ ] Space wire or other communication algorithm
- [ ] Random jumps problem
- [ ] Filter for fusion

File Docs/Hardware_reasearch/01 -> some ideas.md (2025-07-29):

- [ ] Space wire or other communication algorithm
- [ ] Random jumps problem
- [ ] Filter for fusion

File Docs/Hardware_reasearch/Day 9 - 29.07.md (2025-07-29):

### todo:
- [x] Display video feed
- [x] Add 2 way communication
- [x] Add calibration buttons
- [x] Make calibration work
- [x] Make it so you can take and download pictures from the raspberry Pi
- [ ] Calibrate Camera
- [ ] Research communication link with Arduino via protocols like space-wire 
- additional: files are separated to keep things organized 

Problem with transferring the video to another web page some kind of "SSL problem" so i used custom SSL certificate to provide video, from the IP of the raspberry pi to html page on the laptop.
this worked
```bash
openssl req -x509 -newkey rsa:4096 -keyout key.pem -out cert.pem -days 365 -nodes
```

Camera access is very easy. Just use this html line:
```html
<img id="stream" src="https://192.168.55.160:5000/video_feed" alt="Live Stream" width="640">
```

You run ssl on the raspberry pi via:
```python
app.run(host='192.168.55.160', port=5000, ssl_context=('cert.pem', 'key.pem'))
```

#### Threading issue
transfering images and data requires 2 channels:
1.  flask server (port 5000) for image sending
2. websocket (port 6789) for quaternion data
The threading issue was fixed with this command:
```python
flask_thread = threading.Thread(target=run_flask)
flask_thread.daemon = True # Ensure thread exits when main program exits
flask_thread.start()
asyncio.run(main())
```

#### Weird bug?
When sending the quaternion data, we get non-normalized vector, which can be seen as weird distortion of the representation of Three.js. This is probably on the raspberry pi, but the bug wasn't tracked. 
The bug is only visual problem. Easy fix - normalize your data or remove it.

## Current UI progress

![[Screenshot 2025-07-29 at 13-58-42 Three.js Cube with Arrow.png]]

### Library problems and the raw I2C fix - few days ago
Due to the library being shit, the communication is done directly over I2C, ignoring any library we have.

We use `NDOF_FMC_OFF_MODE`, to stop the auto calibration of the *heading*. This allows us to remember the last location and stop auto calibration. Then we can do auto calibration in software.

Sensor connection settings:
```python
ADDR = 0x28 # Or 0x29 depending on BNO055 ADR pin
BUS = 1
```
Specific bits for modes:
```python
OPR_MODE_ADDR = 0x3D
CALIB_STAT = 0x35
CALIBRATION_REG_START = 0x55
CALIBRATION_REG_LEN = 22
CONFIG_MODE = 0x00
NDOF_FMC_OFF_MODE = 0x0C
```
Accessing data of calibration registers:
```python
calib = bus.read_byte_data(ADDR, CALIB_STAT)
sys = (calib >> 6) & 0x03
gyro = (calib >> 4) & 0x03
accel = (calib >> 2) & 0x03
mag = calib & 0x03
```
Euler angles addresses:
```python 
EULER_H_LSB = 0x1A
EULER_R_LSB = 0x1C
EULER_P_LSB = 0x1E
data = bus.read_i2c_block_data(ADDR, EULER_H_LSB, 6) # 2 bytes each for heading, roll, pitch
#convert from little endian signed 16-bit
heading = int.from_bytes(data[0:2], byteorder='little', signed=True) / 16.0
roll = int.from_bytes(data[2:4], byteorder='little', signed=True) / 16.0
pitch = int.from_bytes(data[4:6], byteorder='little', signed=True) / 16.0
```
Quaternion angels addresses:
```python
QUATERNION_REG_START = 0x20
data = bus.read_i2c_block_data(ADDR, QUATERNION_REG_START, 8)
# Convert bytes to 16-bit signed integers
w = int.from_bytes(data[0:2], byteorder='little', signed=True) / (1 << 14)
x = int.from_bytes(data[2:4], byteorder='little', signed=True) / (1 << 14)
y = int.from_bytes(data[4:6], byteorder='little', signed=True) / (1 << 14)
z = int.from_bytes(data[6:8], byteorder='little', signed=True) / (1 << 14)
```

#### Other developments
- Buttons were added for easy control
- Added better text in ssh terminal for better readability when program is looked at

### The normalization problem
Right now the vector is not normalized when calibrated, this can cause a lot of issues. Problem is probably we enter the 4D dimension and lose consistency in scale 

###  The problem where the sd card died
Now i need to download everything

Recovery took from 18:50 to 21:36 (2:30 hours)

Image of the sd card should be made to stop this from happening
Thankfully we had all the scripts on one hand and little damage was done to the actual code

Actually even the quaternion calibration was saved.
Thanks to *vs code* the tabs stored the information from the raspberry pi, and 80 % of the things were extracted from there. The other 20% was simple copy paste

Downloading the libraries took a lot of time. Needed to re-flash once of some problem in apt store and was faster to do this, than search how to fix it, clean up and download all again. 

Restored to this state:
![[Pasted image 20250729213933.png]]

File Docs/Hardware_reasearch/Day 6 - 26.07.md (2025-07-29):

Plans for today:
 - [x] Create Logger program to get info about drift
 - [ ] Research drift correction
 - [x] Research quaternion
 - [x] Reset quaternion  position to identity

Logger program is ready.
```
----------------------- 
 Starting drift test.    
 Don't move the sensor.  
 ----------------------- 
  log file: Log_Logged_Test_Drifting.py_2025-07-26_13-52-40.txt
 >> Setting CONFIG mode to load calibration...
Calibration written to sensor.
 >> Entering NDOF_FMC_OFF mode to lock calibration...
 >> Reading Euler angles | format: (Heading, Roll, Pitch):
Quaternion: w=0.0000, x=0.0000, y=0.0000, z=0.0000
Heading: 0.00°, Roll: 0.00°, Pitch: 0.00°
Quaternion: w=0.8454, x=-0.0146, y=0.0086, z=0.5339
Heading: 295.44°, Roll: -1.69°, Pitch: 0.88°
Quaternion: w=0.8454, x=-0.0146, y=0.0086, z=0.5339
Heading: 295.44°, Roll: -1.69°, Pitch: 0.88°
Quaternion: w=0.8454, x=-0.0146, y=0.0086, z=0.5339
Heading: 295.44°, Roll: -1.69°, Pitch: 0.88°
Quaternion: w=0.8454, x=-0.0146, y=0.0086, z=0.5339
Heading: 295.44°, Roll: -1.69°, Pitch: 0.88°
^CKeyboardInterrupt

 End of program. Exiting...
 ---------------------------- 
 End time 2025-07-26_13-52-42 
 ---------------------------- 
Program ended
```

### Euler rotation on sensor is different conversion

measured shift over 3 hours
```
 Heading: 295.44°, Roll: -1.56°, Pitch: 1.12°

 Heading: 295.44°, Roll: -1.50°, Pitch: 1.19°

 Heading: 295.44°, Roll: -1.50°, Pitch: 1.25°
```

### Quaternion reorientation

[what is quaternion and why is used](https://danceswithcode.net/engineeringnotes/quaternions/quaternions.html)

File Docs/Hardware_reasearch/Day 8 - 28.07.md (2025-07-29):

- [x] fix quaternion information on displayed threejs model
- [x] Make a simple interface for visualization
- [ ] Add button for calibration to (0,0,0)

Made copy of all the scripts of the raspberry pi in case of lose or corruption of the file system on sd card.
Reorganized all the files to 2 folders - Week1 & Week2

Due to not much time I couldn't implement everything for the day

Fixed the coordinates on the three js 3d representation of the satellite 
```javascript
scene.rotation.x = -Math.PI / 2;
```
This rotate the whole axis on x and fixed the visualization issue
Moved the camera to position `(2,2,-5)`

Added labels for better visualizations of the axis
```python
function createLabel(text, position, color = "white") {
const canvas = document.createElement("canvas");
const size = 256;
canvas.width = size;
canvas.height = size;
const context = canvas.getContext("2d");
context.fillStyle = color;
context.font = "bold 100px Arial";
context.textAlign = "center";
context.textBaseline = "middle";
context.fillText(text, size / 2, size / 2);
  
const texture = new THREE.CanvasTexture(canvas);
const material = new THREE.SpriteMaterial({ map: texture, transparent: true });
const sprite = new THREE.Sprite(material);
sprite.scale.set(0.5, 0.5, 0.5); // Adjust label size
sprite.position.copy(position);
return sprite;
} 

// Add labels a bit beyond the arrow tips
const offset = 0.3;
scene.add(createLabel("X", new THREE.Vector3(length + offset, 0, 0), "#ff0000"));
scene.add(createLabel("Y", new THREE.Vector3(0, length + offset, 0), "#00ff00"));
scene.add(createLabel("Z", new THREE.Vector3(0, 0, length + offset), "#0000ff"));
```

redesign the UI to display information in 4 squared 
- received information
- 3d visualization
- quaternion information
- live feed (not currently working, because of threading issues)

This needs to be implemented into movable windows with snap functions. Currently not planing to work on it, because of other important things (calibration)

This protocols are here:
[MIL-STD](https://en.wikipedia.org/wiki/MIL-STD-1553)
[Space Wire](https://en.wikipedia.org/wiki/SpaceWire)
[Cube Sat protocol](https://en.wikipedia.org/wiki/Cubesat_Space_Protocol)

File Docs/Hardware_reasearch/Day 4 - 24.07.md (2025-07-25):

## 3d printer problems
tried chanign settings, tried chanign tube, cleaning extruder

## Hardware updates
- [x] IMU Calibration research
- [ ] IMU Calbiration implementation
- [ ] IMU library check

We have absolute and relative orientation. We need to use absolute, because it uses the magnetic poles. It subject to magnetic interference

~~Quaternion are drift free?~~

link: [datasheet](https://cdn-shop.adafruit.com/datasheets/BST_BNO055_DS000_12.pdf)
to note about IMU: 3.3.3.2 COMPASS
- 3.4 Axis remap
- 3.5.2 Accelerometer configuration (cannot use absolute position without accelerometer)
- 3.6.1 Unit Selection (quaternion setting)
- 3.6.4 Sensor calibration (data registers)
- 3.6.5 Output data registers
- 3.6.5.5 Orientation (Quaternion)
- 3.8.1 Power On Self Test (POST)
- 3.8.2 Build In Self Test (BIST)
- 3.10 Calibration
- 3.10.4 Reuse of Calibration Profile

### Setting Calibration profile
It is important that the correct offsets and corresponding sensor radius are used. Incorrect
offsets may result in unreliable orientation data even at calibration accuracy level 3. To set
the calibration profile the following steps need to be taken
1. Select the operation mode to CONFIG_MODE
2. Write the corresponding sensor offsets and radius data
3. Change operation mode to fusion mode

after page 50 you get only register data and referneces for programming

Good for documentation (page 19)
>> ![[Pasted image 20250724163324.png]]

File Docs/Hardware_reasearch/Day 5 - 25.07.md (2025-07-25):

I'm wired from not seeing significant in my hardware design so I designed a bit of CAD modeling for the CubeSat design.

![[Pasted image 20250725143316.png]]

Now I will do research on IMU in space  

### Research on IMU
A major disadvantage of using IMUs for navigation is that they typically suffer from accumulated error. Because the guidance system is continually integrating acceleration with respect to time to calculate velocity and position _(see [dead reckoning](https://en.wikipedia.org/wiki/Dead_reckoning "Dead reckoning"))_, any measurement errors, however small, are accumulated over time. This leads to 'drift': an ever-increasing difference between where the system thinks it is located and the actual location. Due to integration a constant error in acceleration results in a linear error growth in velocity and a quadratic error growth in position. A constant error in attitude rate (gyro) results in a quadratic error growth in velocity and a cubic error growth in position.[13](https://en.wikipedia.org/wiki/Inertial_measurement_unit#cite_note-13)

A very wide variety of IMUs exists,[14](https://en.wikipedia.org/wiki/Inertial_measurement_unit#cite_note-14) depending on application types, with performance ranging:
- From 0.1°/s to 0.001°/h for gyroscope
- From 100 mg to 10 μg for accelerometers.
To get a rough idea, this means that, for a single, uncorrected accelerometer, the cheapest (at 100 mg) loses its ability to give 50-meter accuracy after around 10 seconds, while the best accelerometer (at 10 μg) loses its 50-meter accuracy after around 17 minutes.[[15]](https://en.wikipedia.org/wiki/Inertial_measurement_unit#cite_note-15)

##### Specifications
16bit gyroscope
triaxial 14bit accelerometer 
full performance geomagnetic sensor

#### use for navigation
ilization and Sl)F-rate 0. I to 10 Hz Up to ma.\imum 0.1 to 50 deg/hr
control SDF-RI vehicle rate
2

#### talk about IMU configuration

#### test result over 2-3 hours
```python
Heading: 270.44°, Roll: 0.38°, Pitch: 1.19°
Heading: 270.44°, Roll: 0.38°, Pitch: 1.19°
Heading: 270.44°, Roll: 0.38°, Pitch: 1.19°
Heading: 270.44°, Roll: 0.38°, Pitch: 1.19°
Heading: 270.44°, Roll: 0.38°, Pitch: 1.19°
Heading: 270.44°, Roll: 0.38°, Pitch: 1.19°
Heading: 270.44°, Roll: 0.38°, Pitch: 1.19°
Heading: 270.44°, Roll: 0.38°, Pitch: 1.19°
Heading: 270.44°, Roll: 0.38°, Pitch: 1.19°
Heading: 270.44°, Roll: 0.38°, Pitch: 1.19°
Heading: 270.44°, Roll: 0.38°, Pitch: 1.19°
Heading: 270.44°, Roll: 0.38°, Pitch: 1.19°
Heading: 270.44°, Roll: 0.38°, Pitch: 1.19°
Heading: 270.44°, Roll: 0.38°, Pitch: 1.19°
Heading: 270.44°, Roll: 0.38°, Pitch: 1.19°
Heading: 270.44°, Roll: 0.38°, Pitch: 1.19°
Heading: 270.44°, Roll: 0.38°, Pitch: 1.19°
Heading: 270.44°, Roll: 0.38°, Pitch: 1.19°
Heading: 270.44°, Roll: 0.38°, Pitch: 1.19°
Heading: 270.44°, Roll: 0.38°, Pitch: 1.19°
Heading: 270.44°, Roll: 0.38°, Pitch: 1.19°
Heading: 270.44°, Roll: 0.38°, Pitch: 1.19°
Heading: 270.44°, Roll: 0.38°, Pitch: 1.19°
Heading: 270.44°, Roll: 0.38°, Pitch: 1.19°
Heading: 270.44°, Roll: 0.38°, Pitch: 1.19°
Heading: 270.44°, Roll: 0.38°, Pitch: 1.19°
Heading: 270.44°, Roll: 0.38°, Pitch: 1.19°
Read from remote host 192.168.55.160: Connection reset by peer
Connection to 192.168.55.160 closed.
client_loop: send disconnect: Broken pipe
[dogw1tfedora]~/Documents/StarTracker/Tsetso's data/Scripts tests/Quaternions Math main
> ssh pi@192.168.55.160
pi@192.168.55.160's password: 
Linux startrack404 6.12.34+rpt-rpi-v8 #1 SMP PREEMPT Debian 1:6.12.34-1+rpt1~bookworm (2025-06-26) aarch64

The programs included with the Debian GNU/Linux system are free software;
the exact distribution terms for each program are described in the
individual files in /usr/share/doc/*/copyright.

Debian GNU/Linux comes with ABSOLUTELY NO WARRANTY, to the extent
permitted by applicable law.
Last login: Fri Jul 25 17:40:23 2025 from 192.168.55.119
pi@startrack404:~ $ ls
CameraServerTest  IMU-Camera_combination  IMU-testing  installPip  legacy-IMU-test  test2.jpg  test3.jpg  test.jpg
pi@startrack404:~ $ ls IMU-testing/
bno055_calibration.json  CalibratonTest1.py  I2CDirectConnectionCalibrationData.py  testConnection2.py
bno055_cal.json          claudeTest          NonMagnetTest.py                       testConnection3.py
CalibrationI2c           compass1.py         Quaternion                             testConnection.py
Calibrationtest2         I2CDetectData.py    StartWithCalibration.py
pi@startrack404:~ $ cd IMU-testing/Quaternion/
pi@startrack404:~/IMU-testing/Quaternion $ ls
conversiontest2.py  testConnection3.py
pi@startrack404:~/IMU-testing/Quaternion $ cd ..
pi@startrack404:~/IMU-testing $ cd ..
pi@startrack404:~ $ ls
CameraServerTest  IMU-Camera_combination  IMU-testing  installPip  legacy-IMU-test  test2.jpg  test3.jpg  test.jpg
pi@startrack404:~ $ ls
CameraServerTest  IMU-Camera_combination  IMU-testing  installPip  legacy-IMU-test  test2.jpg  test3.jpg  test.jpg
pi@startrack404:~ $ ls IMU-Camera_combination/
calibration-test.py  camera_server.py  test2.py  testConnection3.py  test.py
pi@startrack404:~ $ ls
CameraServerTest  IMU-Camera_combination  IMU-testing  installPip  legacy-IMU-test  test2.jpg  test3.jpg  test.jpg
pi@startrack404:~ $ cd IMU-testing/
pi@startrack404:~/IMU-testing $ ls
bno055_calibration.json  CalibratonTest1.py  I2CDirectConnectionCalibrationData.py  testConnection2.py
bno055_cal.json          claudeTest          NonMagnetTest.py                       testConnection3.py
CalibrationI2c           compass1.py         Quaternion                             testConnection.py
Calibrationtest2         I2CDetectData.py    StartWithCalibration.py
pi@startrack404:~/IMU-testing $ python3 StartWithCalibration.py 
Setting CONFIG mode to load calibration...
Calibration written to sensor.
Entering NDOF_FMC_OFF mode to lock calibration...
Reading Euler angles (Heading, Roll, Pitch):
Heading: 0.00°, Roll: 0.00°, Pitch: 0.00°
Heading: 262.25°, Roll: 0.38°, Pitch: 1.88°
Heading: 262.25°, Roll: 0.38°, Pitch: 2.12°
Heading: 262.25°, Roll: 0.38°, Pitch: 2.38°
Heading: 262.25°, Roll: 0.38°, Pitch: 2.50°
Heading: 262.25°, Roll: 0.38°, Pitch: 2.56°
Heading: 262.25°, Roll: 0.38°, Pitch: 2.62°
Heading: 262.25°, Roll: 0.38°, Pitch: 2.62°
Heading: 262.25°, Roll: 0.38°, Pitch: 2.62°
Heading: 262.25°, Roll: 0.38°, Pitch: 2.62°

```

### references
IMU datasheet: https://cdn-shop.adafruit.com/datasheets/BST_BNO055_DS000_12.pdf
Hubble gyro and it's backup plans: https://science.nasa.gov/mission/hubble/observatory/design/hubble-one-gyro-mode/
Gyro developments: https://ntrs.nasa.gov/api/citations/19730003953/downloads/19730003953.pdf

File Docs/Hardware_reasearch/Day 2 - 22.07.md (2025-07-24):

## Raspberry PI setup
Successfully boot raspberry pi with the standard Debian iso, provided from Raspberry pi Imager.

To download it use **raspberry pi imager**. 

click on "operating system" -> "Raspberry Pi (other)" -> "Raspberry Pi OS Lite (32-bit)"

The used settings to log into the raspberry can be found in the other file "Raspberry pi settings". To apply them use CNTR + SHIFT + X

After using ssh to connect to camera, updated the software with
```
sudo apt update && sudo apt full-upgrade
```

Download the needed files for the camera
```
sudo apt install imx500-all
```

after quick shutdown, pluged in the camera, test it with this command:
```
libcamera-still -o test.jpg --nopreview
```

camera output is good, and we can see objects. Needs calibration and look

check out the **camera_server.py**, which is the sample website, that can be used to access life video.

Few thinks to take into account:
On the network of the Hall2, that we are connected to, *Multicast DNS* is **not** active. I check for the IP by making **nmap** (a program for computer network analysis) search for port 22
```
nmap -p 22 --open 192.168.55.0/24
```
after powering the *pi* and waiting for a minute or two i run the same command and compare the outputs to see for new IP address. The comparison is done on random website, just google text comparison.

to connect to raspberry use:
```
ssh <username>@<ip>
```
then login with the password

I used for username: *pi* and for password: *pi*
the IP address i got when connecting to the internet was *192.168.55.160*, but this changes based on many factors (reserved IP's, connected people, if address is already taken, etc.) so check with nmap. 

# Software tests:
## The Astrometry.net test
(any pictures takes of stars, are screenshots on Stellarium version 25.2)

Attempting to use already existing code base (This is command used in Fedora Linux 42):
```
sudo dnf install astrometry astrometry-data
```
I hope this works well and we will have basic simple code and idea.
probably won't be good idea, because we kinda waste time on experimentation without direct output, just knowledge gained, but still a working solution.

After testing: I used this code 
```
solve-field your_image.fits
```
and got very good results.

### Info:
##### pros:
- All the starts are in the right place
- algorithm worked fast on my potato PC
- I think i got 95% accurate coordinates! 
##### cons:
- i need to convert the screenshot from png to **fits** file
- the image was flipped for some reason (maybe conversion problem)

This was the command used to transfer to the specific altitude 
```
core.moveToRaDec("231.399713", "37.926635");
```
Check images in `/Tsetso's data/Scripts tests/astrometry-net` 

There seems to be slightly offset than expected, still very useful!

Output I got on image `sample.fits`:
```
Reading input file 1 of 1: "sample.fits"...
Running command: /usr/bin/image2pnm --infile sample.fits --uncompressed-outfile /tmp/tmp.uncompressed.wOvF52 --outfile /tmp/tmp.ppm.JYKNem --ppm --mydir /usr/bin/solve-field
Extracting sources...
This looks like a multi-color image: processing the first image plane only.  (NAXIS=3)
simplexy: found 735 sources.
Making source extraction overlay plot -- pnmfn = /tmp/tmp.ppm.JYKNem
Solving...
Reading file "./sample.axy"...
Field 1 did not solve (index index-4119.fits, field objects 1-10).
Field 1 did not solve (index index-4118.fits, field objects 1-10).
Field 1 did not solve (index index-4117.fits, field objects 1-10).
Field 1 did not solve (index index-4116.fits, field objects 1-10).
Field 1 did not solve (index index-4115.fits, field objects 1-10).
Field 1 did not solve (index index-4114.fits, field objects 1-10).
Field 1 did not solve (index index-4113.fits, field objects 1-10).
Field 1 did not solve (index index-4112.fits, field objects 1-10).
  log-odds ratio 423.703 (1.02744e+184), 288 match, 25 conflict, 151 distractors, 437 index.
  RA,Dec = (231.371,37.9344), pixel scale 61.0399 arcsec/pix.
  Hit/miss:   Hit/miss: ++++++++++++++++++++++++++++++++++++-+++++++++++++++++++++++++++++++++++++++++++++++++-+++++++++++++
Field 1: solved with index index-4111.fits.
Field 1 solved: writing to file ./sample.solved to indicate this.
Field: sample.fits
Field center: (RA,Dec) = (231.399713, 37.926635) deg.
Field center: (RA H:M:S, Dec D:M:S) = (15:25:35.931, +37:55:35.887).
Field size: 11.3435 x 8.55101 degrees
Field rotation angle: up is -109.23 degrees E of N
Field parity: neg
Creating new FITS file "./sample.new"...
Creating index object overlay plot...
Creating annotation plot...
Your field contains:
  Part of the constellation Bootes (Boo)
  The star Nekkar (β Boo / 42 Boo)
  The star Alkalurops / Inkalunis / Clava / Venabulum (μ1 Boo / 51 Boo A)
  The star Thiba (δ Boo / 49 Boo)
  The star Ceginus (φ Boo / 54 Boo)
  The star μ2 Boo / 51 Boo B
  The star ν1 Boo / 52 Boo
  The star ν2 Boo / 53 Boo
  The star 40 Boo
  The star 50 Boo
  The star ζ1 CrB / ζ2 CrB / 7 CrB
  The star κ CrB / 11 CrB
  The star μ CrB / 6 CrB
```

#### what I think the algorithm is doing:
1. it picks some good star on the picture. I think it chooses based on which ones form a *obtuse triangle (>90 degree angle)*
2. based on this angle it finds in the catalog possible matches
3. ~~catalog can be shrunk to use only >90 angles (not sure tho, this is just my theory)~~  cannot be shrunk, because angles and stuff, don't think about it

#### repeated attempt:
seems that it works, and it is repeatable.
Maybe multiple shots can be taken and taken a medium, we can remove the offset error. There is the problem of slow computation that will make the algorithm very bad.
Possible optimizations:
- smaller catalog of stars to keep track of
- smaller threshold for mapped stars (basically if star is not bright or big enough, it will be excluded in the computations)
- faster methods calculations of angles (not sure if they exist, needs checking)

### Astronometry pytohn
Just to know there is like python script that can be used with our own star tracking. https://pypi.org/project/astrometry/
It can be useful to test our star pixel position determination, compared to already existing ones.
It is different than the other one, because it is python library ( it can be added to your code ), while the *astronometry.net* version is a separate program that can be used independently and just needs image input.

#### Attempt 1 - fail
I tried using this data send in the whatsapp group by Ivaylo
```
  Star 1: (x=959.47, y=539.61)
  Star 2: (x=1878.00, y=404.50)
  Star 3: (x=312.00, y=610.50)
  Star 4: (x=818.86, y=839.27)
  Star 5: (x=48.12, y=744.20)
  Star 6: (x=668.63, y=581.63)
  Star 7: (x=519.38, y=713.62)
  Star 8: (x=45.28, y=668.94)
  Star 9: (x=69.71, y=524.31)
  Star 10: (x=997.68, y=779.32)
  Star 11: (x=1059.28, y=987.44)
  Star 12: (x=1346.90, y=521.10)
  Star 13: (x=767.17, y=291.70)
  Star 14: (x=1133.85, y=121.50)
  Star 15: (x=353.96, y=12.16)
  Star 16: (x=858.17, y=751.07)
  Star 17: (x=22.63, y=714.57)
  Star 18: (x=1092.18, y=251.61)
  Star 19: (x=1121.52, y=897.48)
  Star 20: (x=1387.62, y=527.38)
```
This is based on our own star tracker. Sadly no information was displayed.

### things to note:
scale and arcseconds are important. We better check them out.
`scale (arcsec/pixel) ≈ (206.265 × pixel_size) / focal_length`

it is used here:
```
with astrometry.Solver(
	astrometry.series_5200.index_files(
	cache_directory="astrometry_cache",
	scales={4,5,6},)
) as solver:
```

### uhh.... github?
i was wondering why i cannot upload files on github.. Then i found that the new data is somehow... 2 GIGABYTES!?!??! WHAT DO YOU MEAN????? THERE ARE LIKE 3 PICTURES AND META DATA!!?!?

it was the astronometry cache... i'm tired..
tldr; don't try to upload libraries and enviroment variables to github

## other updates:
Arrived parts 1: camera and IMU
Arrived parts 2: arduinos, some sensors, wires, breadboard, (etc.?)
3d printer saga: nozzle - clogged, sd card slot - still broken; tried cleaning the nozzle, removing it, but it doesn't give up. slot fixed by ignoring it, used *octo pi* installed on another raspberry pi, to control the printer and upload files. new problem: z-axis offset is bad. amazing...

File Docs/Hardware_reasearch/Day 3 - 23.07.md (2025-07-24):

Try offset error fix with full scale image instead of just one screen shot

Takes a long time to figure it out
problem with size of image and spots
checkout:
https://astrometry.net/doc/readme.html

## IMU settings
plan of attack
- [x] connect wires
- [x] get recognized IMU
- [x] get libraries
- [x] get connection
- [x] get data about gyro
- [ ] calibration
- [x] output in website

You need to enable I2c from `raspi-config`
`3 Interface Options` -> `I2C`

some old data:
https://cdn-learn.adafruit.com/downloads/pdf/bno055-absolute-orientation-sensor-with-raspberry-pi-and-beaglebone-black.pdf

setup and documentation:
https://cdn-learn.adafruit.com/downloads/pdf/adafruit-bno055-absolute-orientation-sensor.pdf

This is found in the docs (page 28):
> The exact nature of the calibration process is a black box and not fully documented

Setup the project file systems for bno055 tesitng
```
python3 -m venv .venv
source .venv/bin/activate
pip3 install adafruit-circuitpython-bno055
```
Attempting to update some things, because of error:
```
pip install --upgrade adafruit-circuitpython-busdevice adafruit-circuitpython-bno055
```

setup environment raspberry
```
python3 -m venv .venv
source .venv/bin/activate
```
to exit environment:
```
deactivate
```

testing combination
```
 source .testEnv1/bin/activate
 python3 testConnection3.py 
 pip3 install adafruit-blinka
 pip3 install RPi.GPIO
 pip3 install adafruit-circuitpython-bno055
```

testing data:
```
 pip3 install imutils
```

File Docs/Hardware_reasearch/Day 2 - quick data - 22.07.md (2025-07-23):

Step by step algorithm working:
 1. raw images undergo photometric and geometric calibration
 2. image processing algorithms find candidate stars in the calibrated image
 3. image pixel coordinates for each star centroid is converted to a bearing direction
 4. star identification (ID) algorithms match candidate starbearings to a catalog of known star bearings, and
 5.  pairs of corresponding measured/catalog star bearings are used to compute attitude via a solution to Wahba’s problem. These five tasks are 

Webcam information:
general info - https://www.mouser.bg/new/raspberry-pi/raspberry-pi-ai-camera/
data sheet - https://www.mouser.bg/pdfDocs/ai-camera-product-brief.pdf

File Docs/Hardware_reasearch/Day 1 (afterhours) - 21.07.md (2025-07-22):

https://satsearch.co/products/redwirespace-star-tracker

this states that:
- use quarternions for rotation measurement
- 50-60 main navigation star to determent the satellite position. this are probably big and bright stars, simple constellations, not repeated anywhere
- each picture should have at least 7-10 stars?
- pov of ~19x14 degress
- star catalog is 1889 stars

https://www.ty-space.net/what-is-a-star-tracker-and-how-does-it-work-on-satellites/

used for navigation and exploration, use software to determent position

https://www.mouser.bg/ProductDetail/Raspberry-Pi/SC1174?qs=IKkN%2F947nfBRnuXetv8aQQ%3D%3D
it looks like if this is the sensor, we can implement AI into the project, but I think only one person knows how to develop AI in the team, so Deterministic approach (simple algorithms) will be used.

## idea 1
Using photo resistors (basically sensor that detects light) we can use to see where is the sun and with this information change that orientation to point the camera in other directions, this can be used to estimate general direction of the satellite by having direction via IMU (gyroscope, or a.k.a. angle/rotation knowadge) we can estimate which half of the planet we are on.

Pros:
- simple sensors
- much simple algorithms
Cons:
- basically problems with sun
- no precision (like at all! what do you know? if it is day or night???!?!)
- no on task! maybe can be "supportive sub-sub-system", but that is all. not even useful when other system is active!

### Dark frame
This is frame that is captured while the camera looks at the void of my life or just closed with cap or other dark material. This will catch any problem with camera (e.g. noise) and will be subtracted later to create better, darker image, so that small dots and particles (that only exist because the camera is faulty) are removed from the imaged, before processing

[Dark Frame Computation - page 5](https://ntrs.nasa.gov/api/citations/20200001376/downloads/20200001376.pdf?utm_source=chatgpt.com)

### Some info on star position
You also have a database of stars with known **3D positions in the sky**, expressed as:
- Right Ascension (RA) and Declination (Dec), or
- Unit vectors in some inertial frame (e.g., J2000 coordinate system).

### Problem to solve the orientation - Wahba's problem
Popular algorithms to solve this include:
- **QUEST (QUaternion ESTimator)**
- **SVD-based methods**
- **Davenport’s Q-method**

### Will stars position change if i go to the other side of earth

This is called **annual parallax** when Earth orbits the Sun, and it's used to **measure distances to nearby stars**.

But for most spacecraft applications (especially in Earth orbit), the shift is:
- Less than an **arcsecond** (1/3600 of a degree)
- So small that it's usually **negligible for star tracking**
- Unless you're doing **high-precision astrometry** (like Gaia or Hubble)

### star catalog
using some star catalogs can be very useful and save time on mapping. 
[Tycho-2](https://cdsarc.cds.unistra.fr/viz-bin/cat/I/259#/browse) - too big?
Hipparcos - 

### OK here is the idea
1. We get a image of the stars in the sky. 
2. We find which stars are they.
3. We get their position (a.k.a rotation from earth)
4. we know where we are looking at

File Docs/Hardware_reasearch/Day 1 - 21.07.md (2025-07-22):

basic information

Used raspberry pi imager to install image on device

cannot find raspberry on network

reflash with custom domain active, youtube video said it can be possible to connect to it.
no success, raspberry doesn't connect to network and doesn't show anywhere

3d printer was fixed partially
no extrusion and sd card slot is broken, it doens't lock. the locking mechanism needs to be stopped by bending the metal or changing the sd card slot. Other solution is using one of the raspberry pi's as Octopi and control it remotely

(the files on the sd card are crying for help, last message from cadets last year)

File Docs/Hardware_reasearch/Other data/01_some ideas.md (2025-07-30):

- [ ] Space wire or other communication algorithm
- [x] Random jumps problem
- [ ] Filter for fusion

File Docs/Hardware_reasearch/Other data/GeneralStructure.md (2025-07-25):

# General team structure (for now)

Didi - Mathematics, Algebra, Data manipulation
Ivo - Database, OpenCV camera, Data manipulation
Ale - Documentation, Hardware, Design
Michael - Documentation, CAD design, 3D printing
Tsetso - Hardware, Firmware

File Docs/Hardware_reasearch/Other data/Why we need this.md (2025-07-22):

Orientation of a space craft is very important. From pointing antenna and payload to managing thermals and power. The problem with orienting a craft is that we need information. Data is very important. We need a reliable and repeatable way to get it. One in first glance, very simple and elegant idea is **Star tracking**. Stars don't change so, orientation stays the same. We can track them basically anywhere on earth, and orient based on them. Using simple camera modules with just visible light spectrum, we can get enough information to track data about the direction the spacecraft is facing.

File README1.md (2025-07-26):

# Repo: Star Tracker

**Unofficial Team Name:** 404: Star Not Found

**Unofficial Project Name:** CASSI (Celestial Alignment System for Satellite Inertial-control)

**Official category:** Star tracker 1

**Team Members:**  
Michael Yan, Ivaylo Tsekov, Alexandra Nedela, Dilyana Vasileva, Tsvetomir Staykov

---

## Warning!
This document is subject to change. It is suppost to show the general idea of the project. Ideas, concepts, implemnetation and code may change due to improvements, errors or obsolescence.

**Current status:** 
- check for errors in writing
- need validate
- may be missing subjects
---

## Problem

When you are in space, you need attitude information. This is given with IMU, the but problem comes when you try to calibrate the sensor. Due to accumulation of errors during computation and enviromental variables, effect called "drift" can be found. So how would we determine our correct attitude?

## Project Overview 
This project implements a star tracking system using a **Raspberry Pi** with **(AI) camera** to determine the orientation of the system based on captured star images. Even thought the camera has AI accelerator capabilities, the system uses deterministic algorithm. Once calibrated, the system works in tandem with an IMU (Inertial Measurement Unit) to track orientation without continuous visual input. When drifting accures, due to enviromental variables, power loss or something else, the system automatically recalibrates. 

---

## Current available demo:

Go to folder `digital_twin`. It contains
- `main.py` - main files with all the systems
- `star_distances_sorted.db` - database with calculated angular distances and sorted in ascending order
- `star_identified.png` - sample image from previous tests
- `test_images` - good images from *Stellarium* for testing purposed. Uses specific resolution and FOV

To run the script you will need `sqlite3` and `cv2` libraries installed on you system and *python 3*

To run the script just run:
```bash
python3 main.py 
```
The results should be:
- valid stars that math the Angular distance.
- cordinates of stars found on the picture
- all angular distances that are close to the angular distances of the found stars
- candidates for stars in the python code in format `{star-number} -> [{star 1 hip}, {star 2 hip}, ... {star n hip}]`

## System Architecture

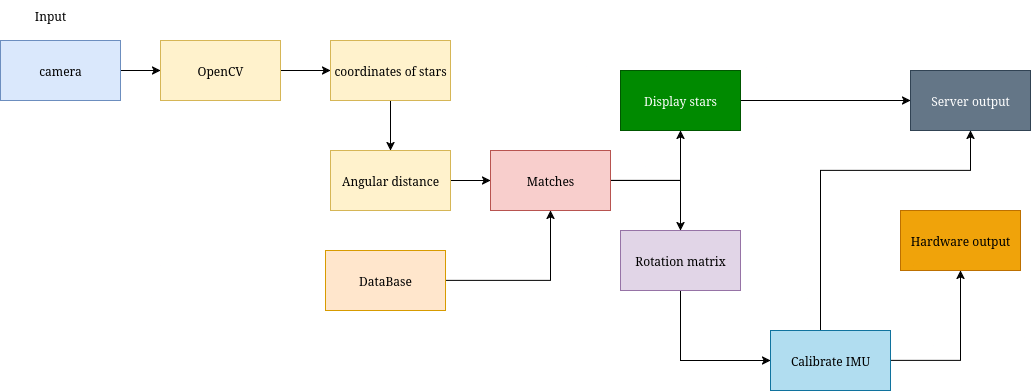
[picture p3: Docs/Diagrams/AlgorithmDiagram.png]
Cool Diagram here cool diagram


### Software

#### Database structure
 We have two tables in our database. **Table 1 - "Stars"** contains the hip of each star according to the hipparcos catalog, the magnitude of each star and x, y, z coordinates of a unit vector coresponding to their RA and DEC coordinates in the equatorial coordinate system.
 **Table 2 - "AngularDistances"** contains the calculated angular distance between each pair of stars in Table 1 sorted from lowes to highest value of angular distance.
 The stars are filtered based on:
  - Brightness
  - Size
  - Eccentricity

#### Lost-in-Space algorithm
 We're implementing a Lost-in-Space approach based on pair matching. The algorithm has four main parts: 1. Image processing and Feature extraction, 2. Angular distance calculations, 3. Mapping to catalog 4. Attitude determination

#### 1. Image Processing and Feature extraction
 The stars in the image are filtered based on: Brightness, Size, Eccentricity.
 Then we select the N brightest stars in our image with blob detection and the cv2 python module. From this we get the (x, y) coordinates of the center of each star in the image.

 Notes and Ideas: 
 - This can and probably should be optimised using a feature extraction algorithm
 - We currently don't account for lense distortion

#### 2. Angular distance calculations
 - We center the (x, y) coordinates of the stars based on our image's center. After which we convert them into vectors with the focal length being the coordinate by the z axis.
 - Convert them into unit vectors to get rid of unnecessary computation
 - Calculate the angular distance between each pair (the cosine of the dot product of the two vectors in the pair)

#### 3. Mapping stars to catalog (To-do)
  - For each pair of stars in our image we query our database to get the possible candidate pairs of stars with an angular distance within a certain tolerance
  - Now for each star in our image both stars in each candidate pair from the db could be the star in our image. How do we figure out the correct mapping? (TO-DO)
  
  Notes and Ideas:
  - the db search could be seriously optimized using a k-vector
  - my idea for the mapping part is to create a graph-like structure where we have the main nodes be the stars from our image and then their adjacency list could be all the candidate stars from the db. After we generate the graph/dict with such structure we could do a traversal algorithm like DFS/BFS excluding an unlikely pair with each recursion/iteration. If this works the final optimisation woud be to do an A* algorithm if I think of a good heuristic.

### Attitude Determination (To-do)

- From the final mapping of each star to a certain hip in our db which we'll get from the step above we can now get the unit vectors for each hip in **Table 1** of our db 
- Determine pitch and yaw based on the known catalog orientation (aligned with the celestial equator)
- Build transformation matrices from:
  - Image star vectors (camera frame)
  - Catalog star vectors (inertial frame)
- Compute the rotational transformation matrix to determine roll
- Convert the final orientation to **quaternions**

---

## Hardware

### Hardware Integration (To-do)

- The initial orientation determined via camera is stored as a reference
- The IMU is zeroed at this orientation
- Subsequent orientation tracking is performed using only the IMU untill it has to be recalibrated again because of the drift

Notes and ideas:
- The simple way to recalibrate would be to just do it after a certain amount of time has passed. However to produce a more accurate orientation in the end we should look into things like Kalman filtering
---

### Mechanical Design

- Modular, layered physical design:
  - Raspberry Pi
  - IMU module
  - Camera mounted perpendicular to the Raspberry Pi board
- 3D CAD models and assembly diagrams are available in the `DOCS/` directory
---

## Current progress

#### Software
 - [x] Define project requirements and needed 
 - [x] Find Algorithm for identification of stars
 - [x] OpenCV star identification on image 
  - [x] Test model with maths on hand
 - [x] Get angular distances between stars
 - [x] Make database of parameters for comparisons (star 1 HIP, star 2 HIP, angular distance)
 - [x] Select candidats for possible stars in specific location
 - [ ] Identify the correct stars
 - [ ] Find rotation matrix
 - [ ] Apply rotation vector to IMU measurements
 - [ ] Test for correctness  

#### Hardware
 - [X] Configure Raspberry pi
 - [X] Connect required modules
  - [X] Camera 
  - [X] IMU (Gyroscope, Accelerometer, Magnetometer)
 - [x] Calibrate on Hardware level IMU
  - [ ] Measure drift
  - [ ] Research drift correction 
 - [ ] Calibrate on Software level IMU
 - [ ] Add interface for communication with Arduino ( I2C is good candidate )
 - [ ] Develop firmware
  - [ ] auto boot configuration

#### CAD
 - [X] Construct simple box for fit testing and simple implementation
 - [X] Make box for better testing and protection
 - [ ] Satellite inclosure with removable modules
  - [ ] Down panel
  - [ ] sliders
  - [ ] test sliders
  - [ ] side protection panels
  - [ ] CASSI module 

#### Additional
 - [ ] Testing | Make black box for testing based on images on monitor
 - [ ] Visualization | Make control panel
  - [ ] 3d visualization
  - [ ] live video 
  - [ ] OpenCV calculations
  - [ ] Control buttons
 - [ ] Check if static ip is needed (just in case)

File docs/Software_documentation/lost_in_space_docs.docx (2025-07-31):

# How we tackled the Lost-in-Space algorithm

## Breakdown:

1. Image processing and Feature extraction
2. Finding the Angular distances
3. Mapping image stars to their IDs
4. Calculating the attitude

### Image processing and Feature extraction

Ivo write your stuff here

### Finding the Angular distances

Since our camera has a diagonal FOV of about 78.6 degrees the images it’ll produce will be almost identical to the gnomonic projection of the stars in our FOV. This allows us to assume a pinhole model of a camera to find the angular distances between stars in our image without accounting for warping.

It allows us to assume a single point through which the light enters our sensor. After which almost all of the needed camera parameters can be calculated using trigonometry ( This is useful because our only way of testing whether or not our approach is correct was through Stellarium which doesn’t give a lot of information except for the vertical FOV and the resolution of the image)

We compute the unit vector for each star selected in the step above using it’s x, y pixel coordinates and the focal length by x or y (since our sensor is not square) as the coordinate of the z axis. Then we normalize the vectors

To find the angular distances between each pair of stars after that becomes a problem of just computing the arcscosine of the dot product of both unit vectors.

The angular distance between two stars in our image is very valuable since it becomes the main reliable parameter by which to determine the stars in our image

### Mapping image stars to their IDs

Now that we have the angular distance for each pair of stars in our image in a hypothetical perfect scenario we can immediately know which pair of stars in our database corresponds to the one in our image. However we run into a few problems:

1. For each pair of stars chosen from our image we have the angular distance calculated, however due to lens distortion and various other factors the offset of some of those stars’s angular distances can reach close to 2 degrees
2. Even if for each pair of stars in our image you had exactly one candidate pair from the database you still wouldn’t know which star in the image pair corresponds to which ID in the database pair
3. In practice due to the angular distance offset the candidates for each image pair become a lot more than one or two since we are working with some tolerances
- How do we solve these problems to get the final mapping?

We decided to look at the problem through the lens of graph theory. If we represent each image star si as a node in a graph with it’s adjacency list being all the possible ID candidates for this star the problem becomes that of graph traversal. We need to start going through the graph, taking a star and one of it’s IDs adding it to the current possible assignment and checking if it meets the geometric requirements of the rest of the assignment so far. For now we don’t need to think about one perfect and full assignment (by full I mean every image star having a catalog ID assignment), we just need to keep track of all correct assignments so far that meet our requirements (Note that we need at least three identified stars to determine our orientation). In our most current implementation we use a DFS (Depth First Search) algorithm with a minimum remaining value heuristic and a hashmap to represent our graph.

Now that we have all possible incomplete or complete assignments we have to figure out how to determine which is the best one. To do that we implemented a scoring system that gives a grade to each solution based on two main factors: difference between image and catalog angular distance and amount of stars identified. A perfect solution that satisfies all requirements would have a score of 0, so in hindsight he smaller the score the better the solution. Which is why out of our solutions we choose the one with the lowest grade.

Now that we have a solution of at least three mappings there’s the problem of outlier assignments that are incorrect. That’s the reason why in practice we make the minimum assignments for each solution a bit higher than 3. We’ll look at a way of tackling the problem outliers in the next section
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

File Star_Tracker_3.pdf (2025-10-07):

## Space Challenges

## Summer 2025

EnduroSat

## A Design Rewiev on CASSI

## Celestial Alignment System for Satellite Inertial-control

Group members:
Michael Yan, Alexandra Nedela, Ivaylo Tsekov, Tsvetomir Staykov, Dilyana Vasileva

Mentor:

Simeon Baltadzhiev

Submitted: 18. August 2025

# Contents

1 Abstract | 1
2 Introduction | 2
3 Research | 6
4 Design | 13

5 Testing | 45
6 Future Work | 55
7 Appendix | 58

# List of Tables
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

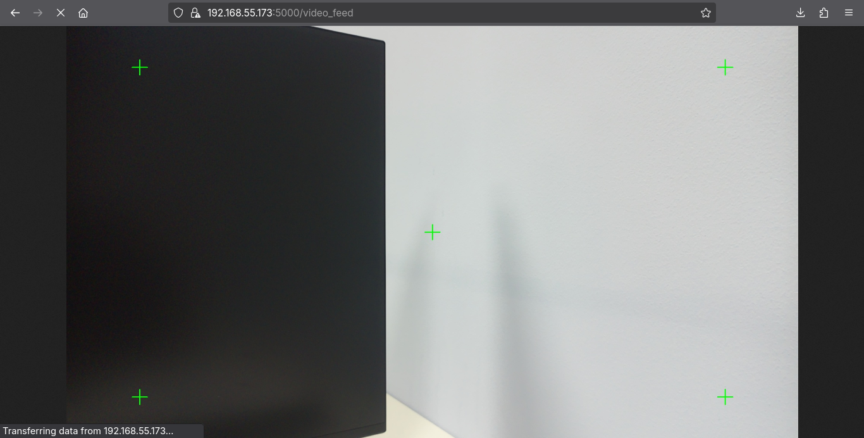
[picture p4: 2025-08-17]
Docs/Hardware_reasearch/Pasted image 20250816202019.png

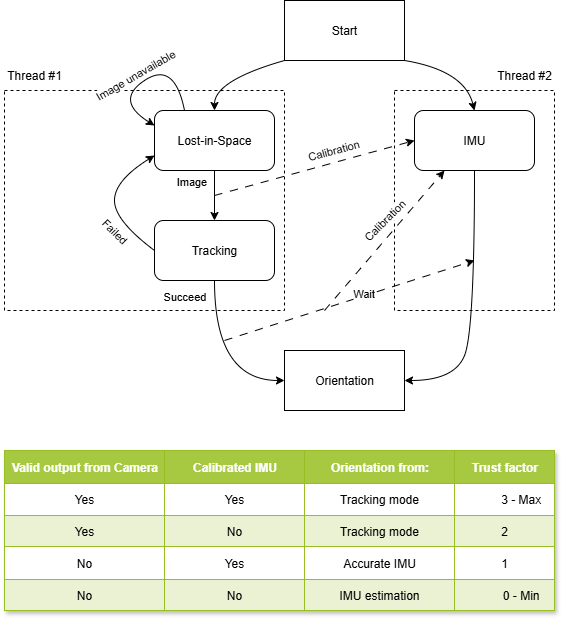
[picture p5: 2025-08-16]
Docs/Hardware_reasearch/Pasted image 20250816101217.png

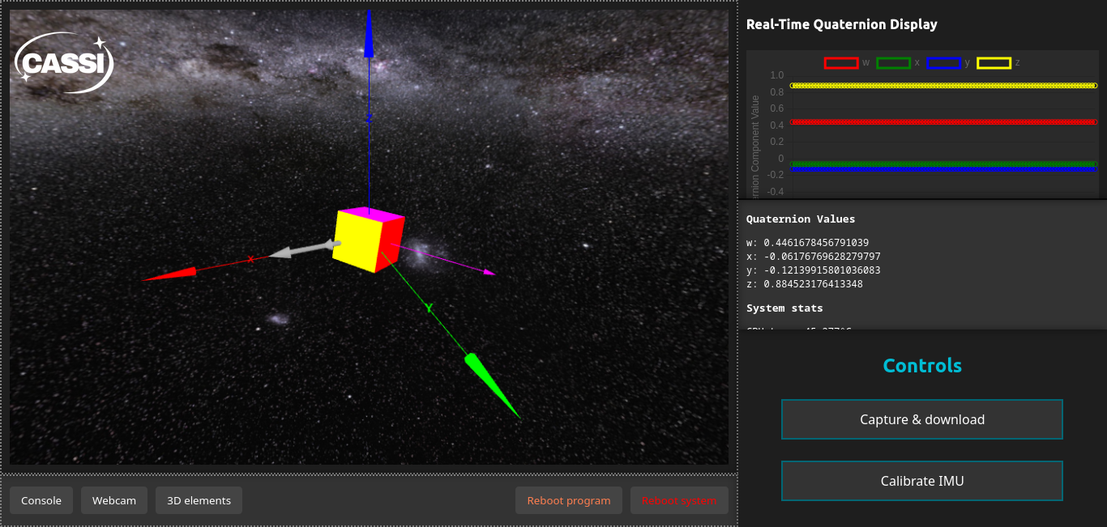
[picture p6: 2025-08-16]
Docs/Hardware_reasearch/Pasted image 20250816112906.png

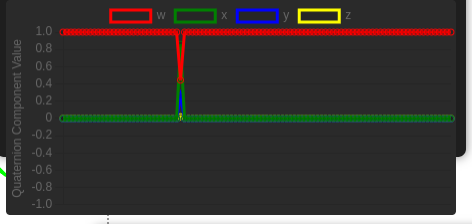
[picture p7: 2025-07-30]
Docs/Hardware_reasearch/Screenshot From 2025-07-30 15-38-25.png

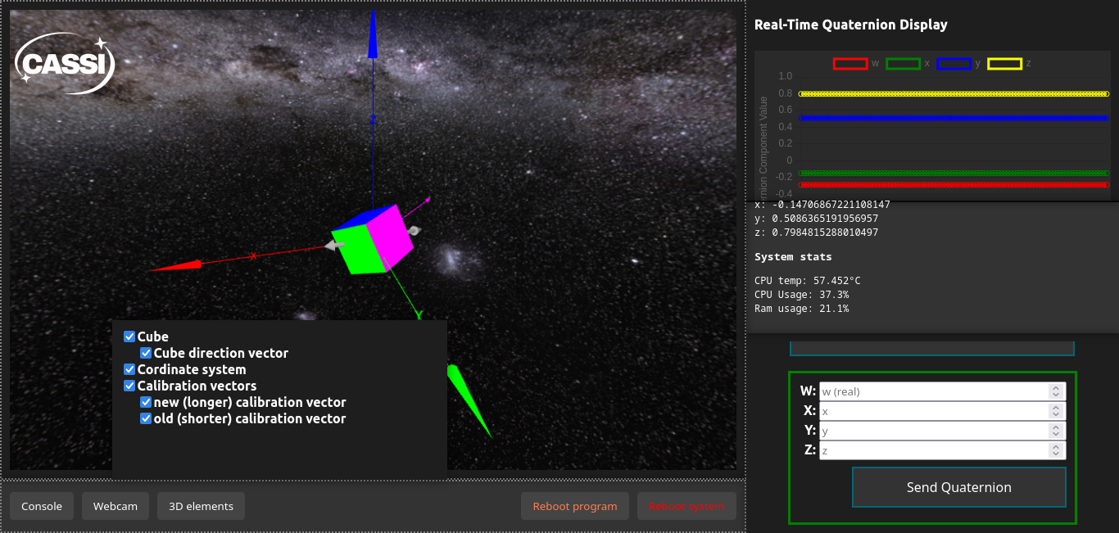
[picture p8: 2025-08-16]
Docs/Hardware_reasearch/Pasted image 20250816113548.png

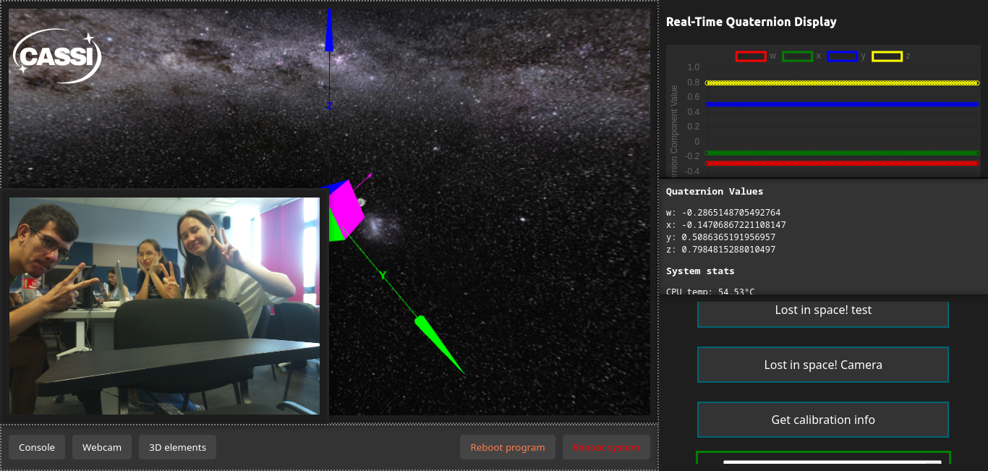
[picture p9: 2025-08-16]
Docs/Hardware_reasearch/Pasted image 20250816113506.png

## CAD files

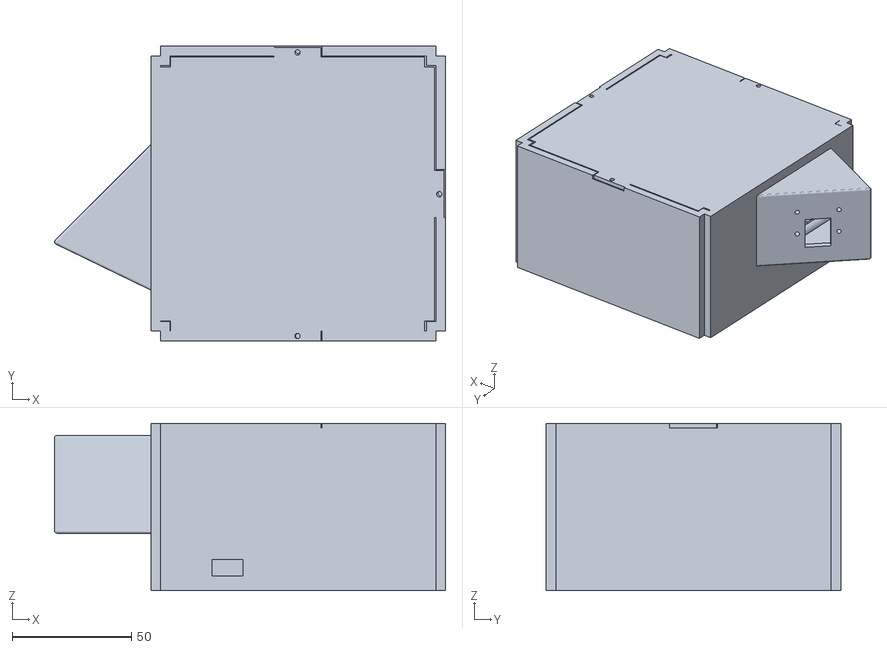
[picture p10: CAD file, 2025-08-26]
DeveloperUI/model.stl
163.8 x 123.4 x 70.0

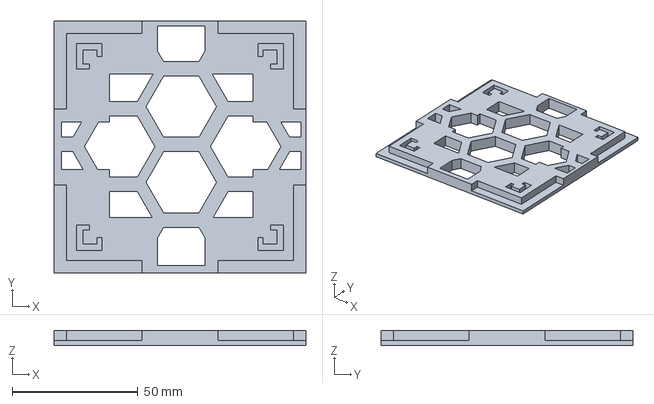
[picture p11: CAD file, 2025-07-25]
Docs/CAD_Concepts/SatDownbase.FCStd
100.0 x 100.0 x 6.00 mm

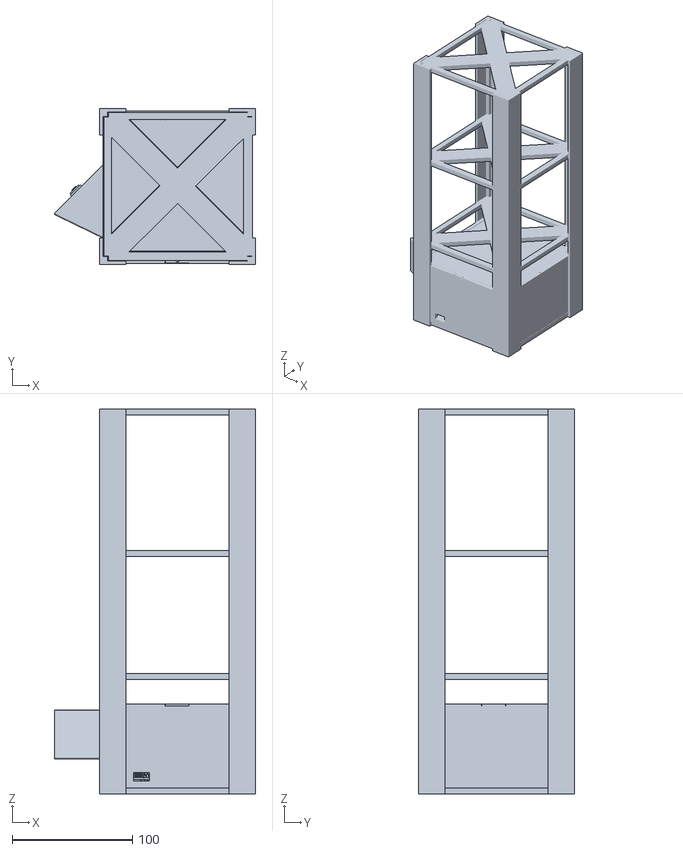
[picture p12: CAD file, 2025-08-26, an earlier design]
DeveloperUI/old_model.stl
167.4 x 130.0 x 320.0

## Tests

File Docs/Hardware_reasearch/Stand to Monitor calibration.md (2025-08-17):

To calibrate the stand for testing the camera with a picture from the screen you can use the pluses/crosses on the  live feed. They are present only on the visualization of the camera from the Flask server, but not in the final image that is processed. Another link to the Flask server path to file `/calibration_overlay` can be use to display on the monitor the calibration image. it will help you match the camera as close as possible to what it should see, if we have direct view toward stars in space. Use program like Stellarium to test your images. Use "F11" to make the browser in full screen and display the image as big as possible.
![[Pasted image 20250816201824.png]]
![[Pasted image 20250816202019.png]]

For the current software version this are always displayed during the live feed. In future 
upgrades they will be toggleable 
### Settings in stellarium !!1! ! seeeee if this exists in the documentation already in different form or something
Use "F3" to rotate to specific object if you want to observe or at specific angle.
Press 'F4" in Stellarium to change the view settings to match the camera. 
The current settings are:
- Projection: Perspective
- Current FOV: 52 degrees 00 minutes 00 seconds
- Labels and Markers: unchecked
- You can remove stars and planet with "P" button. 
- You can remove meteor showers with "CRTL + SHIFT + M".
- Remove HUD with "CTRL + T"
- Remove ground with "G"
- Remove Atmosphere with "A"

Picture with default settings:
![[Pasted image 20250816202409.png]]
Picture with changed settings:
![[Pasted image 20250816202440.png]]

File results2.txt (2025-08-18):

--- Batch Run Started ---
ImageName;Quaternion(w;x;y;z);ExecutionTime_s
Stellarium_test_image_0p00000_30p00000.png001.png;quaternioncoord(0.5831;-0.3697;0.3370;-0.6402);1.1856
Stellarium_test_image_0p00000_60p00000.png001.png;quaternioncoord(-0.6522;0.1909;-0.1751;0.7124);0.8807
Stellarium_test_image_0p00000_90p00000.png001.png;quaternioncoord(-0.6662;0.0000;-0.0003;0.7457);1.2331
Stellarium_test_image_0p00000_m30p00000.png001.png;quaternioncoord(0.2756;-0.7222;0.4782;-0.4170);1.2900
Stellarium_test_image_0p00000_m90p00000.png001.png;quaternioncoord(-0.0001;-0.7546;-0.6561;-0.0004);1.4584
Stellarium_test_image_105p00000_0p00000.png001.png;quaternioncoord(0.6830;-0.6125;-0.3533;-0.1832);1.2537
Stellarium_test_image_105p00000_30p00000.png001.png;quaternioncoord(-0.4690;-0.8739;-0.0110;0.1275);0.7638
Stellarium_test_image_105p00000_60p00000.png001.png;quaternioncoord(0.8092;-0.1729;-0.1923;-0.5276);1.1525
Stellarium_test_image_105p00000_90p00000.png001.png;quaternioncoord(-0.6667;0.0001;-0.0003;0.7453);1.2751
Stellarium_test_image_105p00000_m30p00000.png001.png;quaternioncoord(-0.4851;0.7577;0.4195;0.1211);1.5297
Stellarium_test_image_105p00000_m60p00000.png001.png;quaternioncoord(0.2472;-0.8184;-0.5131;-0.0763);0.7217
Stellarium_test_image_120p00000_0p00000.png001.png;quaternioncoord(-0.0715;0.9489;-0.0760;-0.2979);0.9868
Stellarium_test_image_120p00000_30p00000.png001.png;quaternioncoord(-0.8406;-0.4784;0.1998;-0.1565);1.0360
Stellarium_test_image_120p00000_60p00000.png001.png;quaternioncoord(0.8200;-0.1219;-0.2280;-0.5106);0.6711
Stellarium_test_image_120p00000_90p00000.png001.png;quaternioncoord(-0.6668;0.0000;-0.0003;0.7452);1.2657
Stellarium_test_image_120p00000_m30p00000.png001.png;quaternioncoord(0.4993;-0.7276;-0.4697;-0.0251);0.6573
Stellarium_test_image_120p00000_m60p00000.png001.png;quaternioncoord(0.2579;-0.7981;-0.5442;-0.0197);1.7930
Stellarium_test_image_135p00000_0p00000.png001.png;quaternioncoord(-0.7035;0.5476;0.4474;-0.0706);0.6472
Stellarium_test_image_135p00000_30p00000.png001.png;quaternioncoord(0.3948;-0.1976;0.8935;-0.0822);0.7736
Stellarium_test_image_135p00000_60p00000.png001.png;quaternioncoord(-0.8185;0.0579;0.2519;0.5130);0.6668
Stellarium_test_image_135p00000_90p00000.png001.png;quaternioncoord(-0.6669;0.0000;-0.0003;0.7452);1.2553
Stellarium_test_image_135p00000_m30p00000.png001.png;quaternioncoord(-0.4938;0.7008;0.5089;-0.0780);1.0630
Stellarium_test_image_135p00000_m60p00000.png001.png;quaternioncoord(-0.2557;0.7776;0.5732;-0.0384);1.0749
Stellarium_test_image_150p00000_0p00000.png001.png;quaternioncoord(0.4795;0.2041;0.4940;0.6960);0.8282
Stellarium_test_image_150p00000_30p00000.png001.png;quaternioncoord(-0.4785;0.0481;-0.8715;0.0963);0.7726
Stellarium_test_image_150p00000_60p00000.png001.png;quaternioncoord(-0.7920;-0.0222;0.2575;0.5531);0.6338
Stellarium_test_image_150p00000_90p00000.png001.png;quaternioncoord(-0.6669;0.0000;-0.0003;0.7452);1.1650
Stellarium_test_image_150p00000_m30p00000.png001.png;quaternioncoord(-0.4650;0.6782;0.5387;-0.1833);0.5202
Stellarium_test_image_150p00000_m60p00000.png001.png;quaternioncoord(-0.2405;0.7572;0.5998;-0.0951);0.7903
Stellarium_test_image_150p00000_m90p00000.png001.png;quaternioncoord(-0.0001;-0.7541;-0.6568;-0.0003);1.4500
Stellarium_test_image_15p00000_0p00000.png001.png;quaternioncoord(-0.2566;-0.0460;-0.9412;0.2151);1.2765
Stellarium_test_image_15p00000_30p00000.png001.png;quaternioncoord(0.6044;-0.4361;0.2448;-0.6201);0.7154
Stellarium_test_image_15p00000_60p00000.png001.png;FAILED;0.4370
Stellarium_test_image_15p00000_90p00000.png001.png;quaternioncoord(-0.6663;0.0000;-0.0003;0.7457);1.2396
Stellarium_test_image_15p00000_m30p00000.png001.png;quaternioncoord(0.1464;0.3402;0.6272;0.6852);1.2946
Stellarium_test_image_15p00000_m60p00000.png001.png;quaternioncoord(0.0583;0.8529;0.4532;0.2525);0.6772
Stellarium_test_image_15p00000_m90p00000.png001.png;quaternioncoord(-0.0001;-0.7546;-0.6562;-0.0004);1.3569
Stellarium_test_image_165p00000_0p00000.png001.png;FAILED;0.2845
Stellarium_test_image_165p00000_30p00000.png001.png;quaternioncoord(0.1403;-0.3421;-0.7948;0.4812);1.4460
Stellarium_test_image_165p00000_60p00000.png001.png;quaternioncoord(0.7145;0.1187;-0.2297;-0.6501);0.6894
Stellarium_test_image_165p00000_90p00000.png001.png;quaternioncoord(-0.6670;0.0000;-0.0003;0.7450);1.2700
Stellarium_test_image_165p00000_m30p00000.png001.png;quaternioncoord(-0.4115;0.6594;0.5616;-0.2836);1.2435
Stellarium_test_image_165p00000_m60p00000.png001.png;quaternioncoord(-0.2126;0.7369;0.6246;-0.1471);1.0384
Stellarium_test_image_165p00000_m90p00000.png001.png;quaternioncoord(0.0001;0.7540;0.6569;0.0003);0.6356
Stellarium_test_image_180p00000_0p00000.png001.png;quaternioncoord(-0.2122;-0.8051;0.5319;0.1545);0.9300
Stellarium_test_image_180p00000_30p00000.png001.png;quaternioncoord(-0.4886;0.4130;0.2823;-0.7148);0.9295
Stellarium_test_image_180p00000_60p00000.png001.png;quaternioncoord(-0.5809;-0.2069;0.1553;0.7718);0.4725
Stellarium_test_image_180p00000_90p00000.png001.png;quaternioncoord(-0.6671;0.0000;-0.0003;0.7450);1.2816
Stellarium_test_image_180p00000_m30p00000.png001.png;quaternioncoord(-0.3356;0.6419;0.5816;-0.3703);1.7495
Stellarium_test_image_180p00000_m60p00000.png001.png;quaternioncoord(0.1737;-0.7160;-0.6485;0.1915);0.7052
Stellarium_test_image_180p00000_m90p00000.png001.png;quaternioncoord(-0.0001;-0.7539;-0.6570;-0.0004);1.4610
Stellarium_test_image_195p00000_0p00000.png001.png;quaternioncoord(0.3953;0.3664;0.1929;-0.8199);1.2041
Stellarium_test_image_195p00000_30p00000.png001.png;quaternioncoord(-0.1749;-0.8751;0.4404;0.0978);1.0209
Stellarium_test_image_195p00000_60p00000.png001.png;quaternioncoord(-0.4681;-0.2512;0.0621;0.8449);0.9129
Stellarium_test_image_195p00000_90p00000.png001.png;quaternioncoord(-0.6671;0.0001;-0.0003;0.7449);1.2740
Stellarium_test_image_195p00000_m30p00000.png001.png;quaternioncoord(0.2434;-0.6216;-0.6032;0.4365);1.1046
Stellarium_test_image_195p00000_m60p00000.png001.png;quaternioncoord(0.1256;-0.6943;-0.6717;0.2259);0.7404
Stellarium_test_image_195p00000_m90p00000.png001.png;quaternioncoord(-0.0001;-0.7538;-0.6571;-0.0004);1.3961
Stellarium_test_image_210p00000_0p00000.png001.png;quaternioncoord(-0.1530;0.5223;0.4746;-0.6918);1.2411
Stellarium_test_image_210p00000_30p00000.png001.png;quaternioncoord(0.0158;-0.5537;-0.7305;0.3995);1.1930
Stellarium_test_image_210p00000_60p00000.png001.png;quaternioncoord(-0.4185;-0.2581;-0.0199;0.8706);1.1543
Stellarium_test_image_210p00000_90p00000.png001.png;quaternioncoord(-0.6672;0.0000;-0.0003;0.7448);1.2585
Stellarium_test_image_210p00000_m30p00000.png001.png;quaternioncoord(-0.1428;0.5952;0.6293;-0.4789);0.8324
Stellarium_test_image_210p00000_m60p00000.png001.png;quaternioncoord(0.0714;-0.6705;-0.6955;0.2484);0.7360
Stellarium_test_image_210p00000_m90p00000.png001.png;quaternioncoord(-0.0001;-0.7538;-0.6571;-0.0004);1.3558
Stellarium_test_image_225p00000_0p00000.png001.png;quaternioncoord(0.0282;-0.4797;-0.5198;0.7064);1.3921
Stellarium_test_image_225p00000_30p00000.png001.png;quaternioncoord(-0.0973;-0.3911;-0.3120;0.8604);0.8178
Stellarium_test_image_225p00000_60p00000.png001.png;quaternioncoord(0.4122;0.2437;0.0878;-0.8735);0.7650
Stellarium_test_image_225p00000_90p00000.png001.png;quaternioncoord(-0.6673;0.0000;-0.0003;0.7448);1.2732
Stellarium_test_image_225p00000_m30p00000.png001.png;quaternioncoord(0.0411;-0.5599;-0.6609;0.4980);0.7001
Stellarium_test_image_225p00000_m60p00000.png001.png;quaternioncoord(0.0140;-0.6449;-0.7193;0.2581);0.8022
Stellarium_test_image_225p00000_m90p00000.png001.png;quaternioncoord(-0.0001;-0.7537;-0.6573;-0.0004);1.3669
Stellarium_test_image_240p00000_0p00000.png001.png;quaternioncoord(-0.0974;-0.4346;-0.5581;0.7001);1.6210
Stellarium_test_image_240p00000_30p00000.png001.png;quaternioncoord(0.1995;0.3431;0.3641;-0.8425);1.6457
Stellarium_test_image_240p00000_60p00000.png001.png;quaternioncoord(0.4284;0.2154;0.1438;-0.8657);0.9804
Stellarium_test_image_240p00000_90p00000.png001.png;quaternioncoord(-0.6674;0.0000;-0.0003;0.7447);1.2722
Stellarium_test_image_240p00000_m30p00000.png001.png;quaternioncoord(-0.0560;-0.5143;-0.6970;0.4966);0.8185
Stellarium_test_image_240p00000_m60p00000.png001.png;quaternioncoord(-0.0436;-0.6167;-0.7435;0.2548);0.7822
Stellarium_test_image_240p00000_m90p00000.png001.png;quaternioncoord(-0.0001;-0.7536;-0.6573;-0.0004);1.3683
Stellarium_test_image_255p00000_0p00000.png001.png;quaternioncoord(-0.1944;-0.3638;-0.6066;0.6796);0.9123
Stellarium_test_image_255p00000_30p00000.png001.png;quaternioncoord(0.2859;0.2817;0.4135;-0.8173);1.3368
Stellarium_test_image_255p00000_60p00000.png001.png;quaternioncoord(-0.4554;-0.1770;-0.1893;0.8518);1.0863
Stellarium_test_image_255p00000_90p00000.png001.png;quaternioncoord(-0.6674;0.0000;-0.0003;0.7447);1.2756
Stellarium_test_image_255p00000_m30p00000.png001.png;quaternioncoord(0.1451;0.4574;0.7356;-0.4782);1.1239
Stellarium_test_image_255p00000_m60p00000.png001.png;quaternioncoord(0.0989;0.5872;0.7670;-0.2389);0.7740
Stellarium_test_image_270p00000_0p00000.png001.png;quaternioncoord(-0.4209;0.6216;0.6395;0.1658);0.9490
Stellarium_test_image_270p00000_30p00000.png001.png;quaternioncoord(0.3595;0.2077;0.4552;-0.7877);1.0609
Stellarium_test_image_270p00000_60p00000.png001.png;quaternioncoord(-0.4869;-0.1304;-0.2239;0.8342);1.2350
Stellarium_test_image_270p00000_90p00000.png001.png;quaternioncoord(-0.6675;0.0000;-0.0003;0.7446);1.2701
Stellarium_test_image_270p00000_m30p00000.png001.png;quaternioncoord(-0.2243;-0.3886;-0.7742;0.4465);0.6776
Stellarium_test_image_270p00000_m60p00000.png001.png;quaternioncoord(0.1495;0.5581;0.7885;-0.2109);0.8384
Stellarium_test_image_285p00000_0p00000.png001.png;quaternioncoord(-0.3535;-0.1831;-0.6832;0.6121);0.9764
Stellarium_test_image_285p00000_30p00000.png001.png;quaternioncoord(0.4213;0.1220;0.4852;-0.7564);1.3521
Stellarium_test_image_285p00000_60p00000.png001.png;quaternioncoord(-0.5189;-0.0779;-0.2472;0.8146);1.5855
Stellarium_test_image_285p00000_90p00000.png001.png;quaternioncoord(-0.6675;0.0000;-0.0003;0.7446);1.2739
Stellarium_test_image_285p00000_m30p00000.png001.png;quaternioncoord(0.2921;0.3068;0.8101;-0.4054);0.9583
Stellarium_test_image_285p00000_m60p00000.png001.png;quaternioncoord(0.1938;0.5325;0.8059;-0.1713);1.3137
Stellarium_test_image_300p00000_0p00000.png001.png;quaternioncoord(-0.3980;-0.0527;-0.7054;0.5842);1.1037
Stellarium_test_image_300p00000_30p00000.png001.png;quaternioncoord(0.4718;0.0264;0.4996;-0.7260);1.4392
Stellarium_test_image_300p00000_60p00000.png001.png;quaternioncoord(-0.5499;-0.0213;-0.2583;0.7940);0.7900
Stellarium_test_image_300p00000_90p00000.png001.png;quaternioncoord(-0.6676;0.0000;-0.0003;0.7445);1.2546
Stellarium_test_image_300p00000_m30p00000.png001.png;quaternioncoord(0.3469;0.2088;0.8407;-0.3597);0.8624
Stellarium_test_image_300p00000_m60p00000.png001.png;quaternioncoord(-0.2292;-0.5164;-0.8164;0.1199);1.0274
Stellarium_test_image_30p00000_0p00000.png001.png;quaternioncoord(-0.1060;-0.4276;-0.8382;0.3216);1.0398
Stellarium_test_image_30p00000_30p00000.png001.png;quaternioncoord(0.6303;-0.4789;0.1440;-0.5938);1.4075
Stellarium_test_image_30p00000_60p00000.png001.png;quaternioncoord(0.6988;-0.2483;0.0731;-0.6668);1.0078
Stellarium_test_image_30p00000_90p00000.png001.png;quaternioncoord(-0.6664;0.0000;-0.0003;0.7456);1.2603
Stellarium_test_image_30p00000_m30p00000.png001.png;quaternioncoord(-0.8424;0.1635;-0.4968;-0.1299);1.2568
Stellarium_test_image_30p00000_m60p00000.png001.png;quaternioncoord(-0.0225;0.8756;0.4078;0.2581);0.6209
Stellarium_test_image_30p00000_m90p00000.png001.png;quaternioncoord(-0.0001;-0.7546;-0.6562;-0.0004);1.3607
Stellarium_test_image_315p00000_0p00000.png001.png;FAILED;0.4560
Stellarium_test_image_315p00000_30p00000.png001.png;quaternioncoord(-0.5114;0.0765;-0.4945;0.6987);1.4078
Stellarium_test_image_315p00000_60p00000.png001.png;quaternioncoord(-0.5788;0.0368;-0.2566;0.7732);0.7529
Stellarium_test_image_315p00000_90p00000.png001.png;quaternioncoord(-0.6677;0.0000;-0.0003;0.7444);1.2564
Stellarium_test_image_315p00000_m30p00000.png001.png;quaternioncoord(0.3867;0.0860;0.8619;-0.3165);1.2222
Stellarium_test_image_315p00000_m60p00000.png001.png;quaternioncoord(-0.2527;-0.5203;-0.8138;0.0553);1.0826
Stellarium_test_image_330p00000_0p00000.png001.png;quaternioncoord(-0.1448;-0.0542;0.7580;-0.6336);1.5689
Stellarium_test_image_330p00000_30p00000.png001.png;quaternioncoord(-0.5412;0.1817;-0.4661;0.6758);0.8371
Stellarium_test_image_330p00000_60p00000.png001.png;FAILED;0.5194
Stellarium_test_image_330p00000_90p00000.png001.png;quaternioncoord(-0.6678;0.0000;-0.0003;0.7444);1.2743
Stellarium_test_image_330p00000_m30p00000.png001.png;quaternioncoord(0.2733;0.8122;0.3079;-0.4134);1.3556
Stellarium_test_image_330p00000_m60p00000.png001.png;quaternioncoord(-0.2575;-0.5632;-0.7847;-0.0259);0.7068
Stellarium_test_image_345p00000_0p00000.png001.png;quaternioncoord(0.3974;0.0037;-0.9158;0.0583);1.1946
Stellarium_test_image_345p00000_30p00000.png001.png;quaternioncoord(-0.5643;0.2820;-0.4132;0.6568);1.0596
Stellarium_test_image_345p00000_60p00000.png001.png;quaternioncoord(0.6299;-0.1459;0.2141;-0.7322);1.1393
Stellarium_test_image_345p00000_90p00000.png001.png;quaternioncoord(-0.6678;0.0000;-0.0003;0.7443);1.2806
Stellarium_test_image_345p00000_m30p00000.png001.png;quaternioncoord(-0.2066;0.7971;-0.4607;-0.3313);1.7832
Stellarium_test_image_345p00000_m60p00000.png001.png;quaternioncoord(0.2278;0.6629;0.7024;0.1232);1.0937
Stellarium_test_image_45p00000_0p00000.png001.png;quaternioncoord(0.5193;-0.7066;0.0282;-0.4799);1.3455
Stellarium_test_image_45p00000_30p00000.png001.png;quaternioncoord(-0.6617;0.4982;-0.0423;0.5587);1.7589
Stellarium_test_image_45p00000_60p00000.png001.png;quaternioncoord(0.7227;-0.2583;0.0159;-0.6408);0.7267
Stellarium_test_image_45p00000_90p00000.png001.png;quaternioncoord(-0.6664;-0.0000;-0.0003;0.7456);1.3095
Stellarium_test_image_45p00000_m30p00000.png001.png;quaternioncoord(-0.3114;0.8606;0.0971;0.3911);1.5867
Stellarium_test_image_45p00000_m60p00000.png001.png;quaternioncoord(-0.0896;0.8774;0.4038;0.2430);1.1660
Stellarium_test_image_45p00000_m90p00000.png001.png;quaternioncoord(-0.0001;-0.7544;-0.6564;-0.0004);1.4568
Stellarium_test_image_60p00000_0p00000.png001.png;quaternioncoord(0.5614;-0.7013;-0.0912;-0.4299);0.5287
Stellarium_test_image_60p00000_30p00000.png001.png;quaternioncoord(-0.6976;0.4970;0.0549;0.5132);1.2857
Stellarium_test_image_60p00000_60p00000.png001.png;quaternioncoord(0.7468;-0.2554;-0.0417;-0.6126);1.0809
Stellarium_test_image_60p00000_90p00000.png001.png;quaternioncoord(-0.6665;0.0000;-0.0003;0.7455);1.3214
Stellarium_test_image_60p00000_m30p00000.png001.png;quaternioncoord(0.3639;-0.8430;-0.1986;-0.3428);1.2092
Stellarium_test_image_60p00000_m60p00000.png001.png;quaternioncoord(-0.1451;0.8692;0.4213;0.2145);1.3870
Stellarium_test_image_60p00000_m90p00000.png001.png;quaternioncoord(-0.0001;-0.7544;-0.6564;-0.0004);1.3993
Stellarium_test_image_75p00000_0p00000.png001.png;quaternioncoord(0.6062;-0.6799;-0.1942;-0.3639);0.9561
Stellarium_test_image_75p00000_30p00000.png001.png;quaternioncoord(-0.7359;0.4787;0.1443;0.4566);1.1662
Stellarium_test_image_75p00000_60p00000.png001.png;quaternioncoord(0.7701;-0.2397;-0.0972;-0.5831);0.9720
Stellarium_test_image_75p00000_90p00000.png001.png;quaternioncoord(-0.6665;0.0000;-0.0003;0.7455);1.3196
Stellarium_test_image_75p00000_m30p00000.png001.png;quaternioncoord(0.4134;-0.8179;-0.2846;-0.2812);1.4969
Stellarium_test_image_75p00000_m60p00000.png001.png;quaternioncoord(-0.1900;0.8552;0.4490;0.1758);1.0297
Stellarium_test_image_90p00000_0p00000.png001.png;quaternioncoord(0.6496;-0.6498;-0.2789;-0.2794);1.2547
Stellarium_test_image_90p00000_30p00000.png001.png;quaternioncoord(0.7743;-0.4471;-0.2236;-0.3880);1.6841
Stellarium_test_image_90p00000_60p00000.png001.png;quaternioncoord(-0.7916;0.2121;0.1480;0.5536);1.2628
Stellarium_test_image_90p00000_90p00000.png001.png;quaternioncoord(-0.6666;0.0001;-0.0003;0.7454);1.2754
Stellarium_test_image_90p00000_m30p00000.png001.png;quaternioncoord(0.4552;-0.7885;-0.3580;-0.2070);1.3187
Stellarium_test_image_90p00000_m60p00000.png001.png;quaternioncoord(0.2243;-0.8377;-0.4809;-0.1291);0.6510
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

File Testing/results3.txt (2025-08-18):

--- Batch Run Started ---
ImageName;Quaternion(w;x;y;z;ExecutionTime_s
Stellarium_test_image_0p00000_30p00000.png001.png;0.5831;-0.3697;0.3370;-0.6402;1.1856
Stellarium_test_image_0p00000_60p00000.png001.png;-0.6522;0.1909;-0.1751;0.7124;0.8807
Stellarium_test_image_0p00000_90p00000.png001.png;-0.6662;0.0000;-0.0003;0.7457;1.2331
Stellarium_test_image_0p00000_m30p00000.png001.png;0.2756;-0.7222;0.4782;-0.4170;1.2900
Stellarium_test_image_0p00000_m90p00000.png001.png;-0.0001;-0.7546;-0.6561;-0.0004;1.4584
Stellarium_test_image_105p00000_0p00000.png001.png;0.6830;-0.6125;-0.3533;-0.1832;1.2537
Stellarium_test_image_105p00000_30p00000.png001.png;-0.4690;-0.8739;-0.0110;0.1275;0.7638
Stellarium_test_image_105p00000_60p00000.png001.png;0.8092;-0.1729;-0.1923;-0.5276;1.1525
Stellarium_test_image_105p00000_90p00000.png001.png;-0.6667;0.0001;-0.0003;0.7453;1.2751
Stellarium_test_image_105p00000_m30p00000.png001.png;-0.4851;0.7577;0.4195;0.1211;1.5297
Stellarium_test_image_105p00000_m60p00000.png001.png;0.2472;-0.8184;-0.5131;-0.0763;0.7217
Stellarium_test_image_120p00000_0p00000.png001.png;-0.0715;0.9489;-0.0760;-0.2979;0.9868
Stellarium_test_image_120p00000_30p00000.png001.png;-0.8406;-0.4784;0.1998;-0.1565;1.0360
Stellarium_test_image_120p00000_60p00000.png001.png;0.8200;-0.1219;-0.2280;-0.5106;0.6711
Stellarium_test_image_120p00000_90p00000.png001.png;-0.6668;0.0000;-0.0003;0.7452;1.2657
Stellarium_test_image_120p00000_m30p00000.png001.png;0.4993;-0.7276;-0.4697;-0.0251;0.6573
Stellarium_test_image_120p00000_m60p00000.png001.png;0.2579;-0.7981;-0.5442;-0.0197;1.7930
Stellarium_test_image_135p00000_0p00000.png001.png;-0.7035;0.5476;0.4474;-0.0706;0.6472
Stellarium_test_image_135p00000_30p00000.png001.png;0.3948;-0.1976;0.8935;-0.0822;0.7736
Stellarium_test_image_135p00000_60p00000.png001.png;-0.8185;0.0579;0.2519;0.5130;0.6668
Stellarium_test_image_135p00000_90p00000.png001.png;-0.6669;0.0000;-0.0003;0.7452;1.2553
Stellarium_test_image_135p00000_m30p00000.png001.png;-0.4938;0.7008;0.5089;-0.0780;1.0630
Stellarium_test_image_135p00000_m60p00000.png001.png;-0.2557;0.7776;0.5732;-0.0384;1.0749
Stellarium_test_image_150p00000_0p00000.png001.png;0.4795;0.2041;0.4940;0.6960;0.8282
Stellarium_test_image_150p00000_30p00000.png001.png;-0.4785;0.0481;-0.8715;0.0963;0.7726
Stellarium_test_image_150p00000_60p00000.png001.png;-0.7920;-0.0222;0.2575;0.5531;0.6338
Stellarium_test_image_150p00000_90p00000.png001.png;-0.6669;0.0000;-0.0003;0.7452;1.1650
Stellarium_test_image_150p00000_m30p00000.png001.png;-0.4650;0.6782;0.5387;-0.1833;0.5202
Stellarium_test_image_150p00000_m60p00000.png001.png;-0.2405;0.7572;0.5998;-0.0951;0.7903
Stellarium_test_image_150p00000_m90p00000.png001.png;-0.0001;-0.7541;-0.6568;-0.0003;1.4500
Stellarium_test_image_15p00000_0p00000.png001.png;-0.2566;-0.0460;-0.9412;0.2151;1.2765
Stellarium_test_image_15p00000_30p00000.png001.png;0.6044;-0.4361;0.2448;-0.6201;0.7154
Stellarium_test_image_15p00000_60p00000.png001.png;FAILED;0.4370
Stellarium_test_image_15p00000_90p00000.png001.png;-0.6663;0.0000;-0.0003;0.7457;1.2396
Stellarium_test_image_15p00000_m30p00000.png001.png;0.1464;0.3402;0.6272;0.6852;1.2946
Stellarium_test_image_15p00000_m60p00000.png001.png;0.0583;0.8529;0.4532;0.2525;0.6772
Stellarium_test_image_15p00000_m90p00000.png001.png;-0.0001;-0.7546;-0.6562;-0.0004;1.3569
Stellarium_test_image_165p00000_0p00000.png001.png;FAILED;0.2845
Stellarium_test_image_165p00000_30p00000.png001.png;0.1403;-0.3421;-0.7948;0.4812;1.4460
Stellarium_test_image_165p00000_60p00000.png001.png;0.7145;0.1187;-0.2297;-0.6501;0.6894
Stellarium_test_image_165p00000_90p00000.png001.png;-0.6670;0.0000;-0.0003;0.7450;1.2700
Stellarium_test_image_165p00000_m30p00000.png001.png;-0.4115;0.6594;0.5616;-0.2836;1.2435
Stellarium_test_image_165p00000_m60p00000.png001.png;-0.2126;0.7369;0.6246;-0.1471;1.0384
Stellarium_test_image_165p00000_m90p00000.png001.png;0.0001;0.7540;0.6569;0.0003;0.6356
Stellarium_test_image_180p00000_0p00000.png001.png;-0.2122;-0.8051;0.5319;0.1545;0.9300
Stellarium_test_image_180p00000_30p00000.png001.png;-0.4886;0.4130;0.2823;-0.7148;0.9295
Stellarium_test_image_180p00000_60p00000.png001.png;-0.5809;-0.2069;0.1553;0.7718;0.4725
Stellarium_test_image_180p00000_90p00000.png001.png;-0.6671;0.0000;-0.0003;0.7450;1.2816
Stellarium_test_image_180p00000_m30p00000.png001.png;-0.3356;0.6419;0.5816;-0.3703;1.7495
Stellarium_test_image_180p00000_m60p00000.png001.png;0.1737;-0.7160;-0.6485;0.1915;0.7052
Stellarium_test_image_180p00000_m90p00000.png001.png;-0.0001;-0.7539;-0.6570;-0.0004;1.4610
Stellarium_test_image_195p00000_0p00000.png001.png;0.3953;0.3664;0.1929;-0.8199;1.2041
Stellarium_test_image_195p00000_30p00000.png001.png;-0.1749;-0.8751;0.4404;0.0978;1.0209
Stellarium_test_image_195p00000_60p00000.png001.png;-0.4681;-0.2512;0.0621;0.8449;0.9129
Stellarium_test_image_195p00000_90p00000.png001.png;-0.6671;0.0001;-0.0003;0.7449;1.2740
Stellarium_test_image_195p00000_m30p00000.png001.png;0.2434;-0.6216;-0.6032;0.4365;1.1046
Stellarium_test_image_195p00000_m60p00000.png001.png;0.1256;-0.6943;-0.6717;0.2259;0.7404
Stellarium_test_image_195p00000_m90p00000.png001.png;-0.0001;-0.7538;-0.6571;-0.0004;1.3961
Stellarium_test_image_210p00000_0p00000.png001.png;-0.1530;0.5223;0.4746;-0.6918;1.2411
Stellarium_test_image_210p00000_30p00000.png001.png;0.0158;-0.5537;-0.7305;0.3995;1.1930
Stellarium_test_image_210p00000_60p00000.png001.png;-0.4185;-0.2581;-0.0199;0.8706;1.1543
Stellarium_test_image_210p00000_90p00000.png001.png;-0.6672;0.0000;-0.0003;0.7448;1.2585
Stellarium_test_image_210p00000_m30p00000.png001.png;-0.1428;0.5952;0.6293;-0.4789;0.8324
Stellarium_test_image_210p00000_m60p00000.png001.png;0.0714;-0.6705;-0.6955;0.2484;0.7360
Stellarium_test_image_210p00000_m90p00000.png001.png;-0.0001;-0.7538;-0.6571;-0.0004;1.3558
Stellarium_test_image_225p00000_0p00000.png001.png;0.0282;-0.4797;-0.5198;0.7064;1.3921
Stellarium_test_image_225p00000_30p00000.png001.png;-0.0973;-0.3911;-0.3120;0.8604;0.8178
Stellarium_test_image_225p00000_60p00000.png001.png;0.4122;0.2437;0.0878;-0.8735;0.7650
Stellarium_test_image_225p00000_90p00000.png001.png;-0.6673;0.0000;-0.0003;0.7448;1.2732
Stellarium_test_image_225p00000_m30p00000.png001.png;0.0411;-0.5599;-0.6609;0.4980;0.7001
Stellarium_test_image_225p00000_m60p00000.png001.png;0.0140;-0.6449;-0.7193;0.2581;0.8022
Stellarium_test_image_225p00000_m90p00000.png001.png;-0.0001;-0.7537;-0.6573;-0.0004;1.3669
Stellarium_test_image_240p00000_0p00000.png001.png;-0.0974;-0.4346;-0.5581;0.7001;1.6210
Stellarium_test_image_240p00000_30p00000.png001.png;0.1995;0.3431;0.3641;-0.8425;1.6457
Stellarium_test_image_240p00000_60p00000.png001.png;0.4284;0.2154;0.1438;-0.8657;0.9804
Stellarium_test_image_240p00000_90p00000.png001.png;-0.6674;0.0000;-0.0003;0.7447;1.2722
Stellarium_test_image_240p00000_m30p00000.png001.png;-0.0560;-0.5143;-0.6970;0.4966;0.8185
Stellarium_test_image_240p00000_m60p00000.png001.png;-0.0436;-0.6167;-0.7435;0.2548;0.7822
Stellarium_test_image_240p00000_m90p00000.png001.png;-0.0001;-0.7536;-0.6573;-0.0004;1.3683
Stellarium_test_image_255p00000_0p00000.png001.png;-0.1944;-0.3638;-0.6066;0.6796;0.9123
Stellarium_test_image_255p00000_30p00000.png001.png;0.2859;0.2817;0.4135;-0.8173;1.3368
Stellarium_test_image_255p00000_60p00000.png001.png;-0.4554;-0.1770;-0.1893;0.8518;1.0863
Stellarium_test_image_255p00000_90p00000.png001.png;-0.6674;0.0000;-0.0003;0.7447;1.2756
Stellarium_test_image_255p00000_m30p00000.png001.png;0.1451;0.4574;0.7356;-0.4782;1.1239
Stellarium_test_image_255p00000_m60p00000.png001.png;0.0989;0.5872;0.7670;-0.2389;0.7740
Stellarium_test_image_270p00000_0p00000.png001.png;-0.4209;0.6216;0.6395;0.1658;0.9490
Stellarium_test_image_270p00000_30p00000.png001.png;0.3595;0.2077;0.4552;-0.7877;1.0609
Stellarium_test_image_270p00000_60p00000.png001.png;-0.4869;-0.1304;-0.2239;0.8342;1.2350
Stellarium_test_image_270p00000_90p00000.png001.png;-0.6675;0.0000;-0.0003;0.7446;1.2701
Stellarium_test_image_270p00000_m30p00000.png001.png;-0.2243;-0.3886;-0.7742;0.4465;0.6776
Stellarium_test_image_270p00000_m60p00000.png001.png;0.1495;0.5581;0.7885;-0.2109;0.8384
Stellarium_test_image_285p00000_0p00000.png001.png;-0.3535;-0.1831;-0.6832;0.6121;0.9764
Stellarium_test_image_285p00000_30p00000.png001.png;0.4213;0.1220;0.4852;-0.7564;1.3521
Stellarium_test_image_285p00000_60p00000.png001.png;-0.5189;-0.0779;-0.2472;0.8146;1.5855
Stellarium_test_image_285p00000_90p00000.png001.png;-0.6675;0.0000;-0.0003;0.7446;1.2739
Stellarium_test_image_285p00000_m30p00000.png001.png;0.2921;0.3068;0.8101;-0.4054;0.9583
Stellarium_test_image_285p00000_m60p00000.png001.png;0.1938;0.5325;0.8059;-0.1713;1.3137
Stellarium_test_image_300p00000_0p00000.png001.png;-0.3980;-0.0527;-0.7054;0.5842;1.1037
Stellarium_test_image_300p00000_30p00000.png001.png;0.4718;0.0264;0.4996;-0.7260;1.4392
Stellarium_test_image_300p00000_60p00000.png001.png;-0.5499;-0.0213;-0.2583;0.7940;0.7900
Stellarium_test_image_300p00000_90p00000.png001.png;-0.6676;0.0000;-0.0003;0.7445;1.2546
Stellarium_test_image_300p00000_m30p00000.png001.png;0.3469;0.2088;0.8407;-0.3597;0.8624
Stellarium_test_image_300p00000_m60p00000.png001.png;-0.2292;-0.5164;-0.8164;0.1199;1.0274
Stellarium_test_image_30p00000_0p00000.png001.png;-0.1060;-0.4276;-0.8382;0.3216;1.0398
Stellarium_test_image_30p00000_30p00000.png001.png;0.6303;-0.4789;0.1440;-0.5938;1.4075
Stellarium_test_image_30p00000_60p00000.png001.png;0.6988;-0.2483;0.0731;-0.6668;1.0078
Stellarium_test_image_30p00000_90p00000.png001.png;-0.6664;0.0000;-0.0003;0.7456;1.2603
Stellarium_test_image_30p00000_m30p00000.png001.png;-0.8424;0.1635;-0.4968;-0.1299;1.2568
Stellarium_test_image_30p00000_m60p00000.png001.png;-0.0225;0.8756;0.4078;0.2581;0.6209
Stellarium_test_image_30p00000_m90p00000.png001.png;-0.0001;-0.7546;-0.6562;-0.0004;1.3607
Stellarium_test_image_315p00000_0p00000.png001.png;FAILED;0.4560
Stellarium_test_image_315p00000_30p00000.png001.png;-0.5114;0.0765;-0.4945;0.6987;1.4078
Stellarium_test_image_315p00000_60p00000.png001.png;-0.5788;0.0368;-0.2566;0.7732;0.7529
Stellarium_test_image_315p00000_90p00000.png001.png;-0.6677;0.0000;-0.0003;0.7444;1.2564
Stellarium_test_image_315p00000_m30p00000.png001.png;0.3867;0.0860;0.8619;-0.3165;1.2222
Stellarium_test_image_315p00000_m60p00000.png001.png;-0.2527;-0.5203;-0.8138;0.0553;1.0826
Stellarium_test_image_330p00000_0p00000.png001.png;-0.1448;-0.0542;0.7580;-0.6336;1.5689
Stellarium_test_image_330p00000_30p00000.png001.png;-0.5412;0.1817;-0.4661;0.6758;0.8371
Stellarium_test_image_330p00000_60p00000.png001.png;FAILED;0.5194
Stellarium_test_image_330p00000_90p00000.png001.png;-0.6678;0.0000;-0.0003;0.7444;1.2743
Stellarium_test_image_330p00000_m30p00000.png001.png;0.2733;0.8122;0.3079;-0.4134;1.3556
Stellarium_test_image_330p00000_m60p00000.png001.png;-0.2575;-0.5632;-0.7847;-0.0259;0.7068
Stellarium_test_image_345p00000_0p00000.png001.png;0.3974;0.0037;-0.9158;0.0583;1.1946
Stellarium_test_image_345p00000_30p00000.png001.png;-0.5643;0.2820;-0.4132;0.6568;1.0596
Stellarium_test_image_345p00000_60p00000.png001.png;0.6299;-0.1459;0.2141;-0.7322;1.1393
Stellarium_test_image_345p00000_90p00000.png001.png;-0.6678;0.0000;-0.0003;0.7443;1.2806
Stellarium_test_image_345p00000_m30p00000.png001.png;-0.2066;0.7971;-0.4607;-0.3313;1.7832
Stellarium_test_image_345p00000_m60p00000.png001.png;0.2278;0.6629;0.7024;0.1232;1.0937
Stellarium_test_image_45p00000_0p00000.png001.png;0.5193;-0.7066;0.0282;-0.4799;1.3455
Stellarium_test_image_45p00000_30p00000.png001.png;-0.6617;0.4982;-0.0423;0.5587;1.7589
Stellarium_test_image_45p00000_60p00000.png001.png;0.7227;-0.2583;0.0159;-0.6408;0.7267
Stellarium_test_image_45p00000_90p00000.png001.png;-0.6664;-0.0000;-0.0003;0.7456;1.3095
Stellarium_test_image_45p00000_m30p00000.png001.png;-0.3114;0.8606;0.0971;0.3911;1.5867
Stellarium_test_image_45p00000_m60p00000.png001.png;-0.0896;0.8774;0.4038;0.2430;1.1660
Stellarium_test_image_45p00000_m90p00000.png001.png;-0.0001;-0.7544;-0.6564;-0.0004;1.4568
Stellarium_test_image_60p00000_0p00000.png001.png;0.5614;-0.7013;-0.0912;-0.4299;0.5287
Stellarium_test_image_60p00000_30p00000.png001.png;-0.6976;0.4970;0.0549;0.5132;1.2857
Stellarium_test_image_60p00000_60p00000.png001.png;0.7468;-0.2554;-0.0417;-0.6126;1.0809
Stellarium_test_image_60p00000_90p00000.png001.png;-0.6665;0.0000;-0.0003;0.7455;1.3214
Stellarium_test_image_60p00000_m30p00000.png001.png;0.3639;-0.8430;-0.1986;-0.3428;1.2092
Stellarium_test_image_60p00000_m60p00000.png001.png;-0.1451;0.8692;0.4213;0.2145;1.3870
Stellarium_test_image_60p00000_m90p00000.png001.png;-0.0001;-0.7544;-0.6564;-0.0004;1.3993
Stellarium_test_image_75p00000_0p00000.png001.png;0.6062;-0.6799;-0.1942;-0.3639;0.9561
Stellarium_test_image_75p00000_30p00000.png001.png;-0.7359;0.4787;0.1443;0.4566;1.1662
Stellarium_test_image_75p00000_60p00000.png001.png;0.7701;-0.2397;-0.0972;-0.5831;0.9720
Stellarium_test_image_75p00000_90p00000.png001.png;-0.6665;0.0000;-0.0003;0.7455;1.3196
Stellarium_test_image_75p00000_m30p00000.png001.png;0.4134;-0.8179;-0.2846;-0.2812;1.4969
Stellarium_test_image_75p00000_m60p00000.png001.png;-0.1900;0.8552;0.4490;0.1758;1.0297
Stellarium_test_image_90p00000_0p00000.png001.png;0.6496;-0.6498;-0.2789;-0.2794;1.2547
Stellarium_test_image_90p00000_30p00000.png001.png;0.7743;-0.4471;-0.2236;-0.3880;1.6841
Stellarium_test_image_90p00000_60p00000.png001.png;-0.7916;0.2121;0.1480;0.5536;1.2628
Stellarium_test_image_90p00000_90p00000.png001.png;-0.6666;0.0001;-0.0003;0.7454;1.2754
Stellarium_test_image_90p00000_m30p00000.png001.png;0.4552;-0.7885;-0.3580;-0.2070;1.3187
Stellarium_test_image_90p00000_m60p00000.png001.png;0.2243;-0.8377;-0.4809;-0.1291;0.6510
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

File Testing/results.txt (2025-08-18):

--- Batch Run Started ---
ImageName;Quaternion(w;x;y;z);ExecutionTime_s
Stellarium_test_image_0p00000_0p00000.png001.png;quaternioncoord(-0.4650;0.5326;-0.4654;0.5326);3.5634
Stellarium_test_image_0p00000_30p00000.png001.png;quaternioncoord(-0.5831;0.3696;-0.3370;0.6402);1.9974
Stellarium_test_image_0p00000_60p00000.png001.png;quaternioncoord(-0.6522;0.1909;-0.1750;0.7124);2.1827
Stellarium_test_image_0p00000_90p00000.png001.png;quaternioncoord(-0.6662;-0.0000;-0.0003;0.7458);1.9504
Stellarium_test_image_0p00000_m30p00000.png001.png;quaternioncoord(-0.2757;0.7222;-0.4781;0.4170);1.6652
Stellarium_test_image_0p00000_m90p00000.png001.png;quaternioncoord(-0.0001;-0.7547;-0.6561;-0.0002);2.1635
Stellarium_test_image_105p00000_0p00000.png001.png;quaternioncoord(0.6830;-0.6125;-0.3534;-0.1831);1.8575
Stellarium_test_image_105p00000_30p00000.png001.png;quaternioncoord(0.8100;-0.4060;-0.2917;-0.3064);2.5925
Stellarium_test_image_105p00000_60p00000.png001.png;quaternioncoord(-0.8092;0.1729;0.1924;0.5275);1.6921
Stellarium_test_image_105p00000_90p00000.png001.png;quaternioncoord(-0.6667;-0.0000;-0.0003;0.7453);1.9481
Stellarium_test_image_105p00000_m30p00000.png001.png;quaternioncoord(-0.4851;0.7577;0.4195;0.1210);2.3388
Stellarium_test_image_105p00000_m60p00000.png001.png;quaternioncoord(0.2473;-0.8184;-0.5132;-0.0763);2.1391
Stellarium_test_image_120p00000_0p00000.png001.png;quaternioncoord(0.7040;-0.5768;-0.4091;-0.0661);8.8091
Stellarium_test_image_120p00000_30p00000.png001.png;FAILED;7.9237
Stellarium_test_image_120p00000_60p00000.png001.png;quaternioncoord(-0.8201;0.1219;0.2281;0.5105);0.9557
Stellarium_test_image_120p00000_90p00000.png001.png;quaternioncoord(-0.6668;-0.0000;-0.0003;0.7453);1.9793
Stellarium_test_image_120p00000_m30p00000.png001.png;quaternioncoord(0.4993;-0.7276;-0.4697;-0.0250);1.7877
Stellarium_test_image_120p00000_m60p00000.png001.png;quaternioncoord(0.2580;-0.7981;-0.5442;-0.0196);2.1252
Stellarium_test_image_135p00000_0p00000.png001.png;quaternioncoord(0.7035;-0.5476;-0.4475;0.0705);8.2627
Stellarium_test_image_135p00000_30p00000.png001.png;quaternioncoord(0.8617;-0.3165;-0.3870;-0.0867);9.3099
Stellarium_test_image_135p00000_60p00000.png001.png;quaternioncoord(-0.8186;0.0579;0.2520;0.5129);0.8266
Stellarium_test_image_135p00000_90p00000.png001.png;quaternioncoord(-0.6668;-0.0000;-0.0003;0.7452);2.0021
Stellarium_test_image_135p00000_m30p00000.png001.png;quaternioncoord(0.4938;-0.7007;-0.5090;0.0781);1.9194
Stellarium_test_image_135p00000_m60p00000.png001.png;quaternioncoord(0.2558;-0.7776;-0.5731;0.0385);2.3389
Stellarium_test_image_150p00000_0p00000.png001.png;FAILED;9.2528
Stellarium_test_image_150p00000_30p00000.png001.png;FAILED;4.4666
Stellarium_test_image_150p00000_60p00000.png001.png;quaternioncoord(0.7920;0.0223;-0.2576;-0.5531);0.8373
Stellarium_test_image_150p00000_90p00000.png001.png;quaternioncoord(-0.6669;-0.0000;-0.0003;0.7451);1.8695
Stellarium_test_image_150p00000_m30p00000.png001.png;quaternioncoord(-0.4650;0.6782;0.5387;-0.1834);1.0018
Stellarium_test_image_150p00000_m60p00000.png001.png;quaternioncoord(0.2405;-0.7572;-0.5998;0.0951);2.1660
Stellarium_test_image_150p00000_m90p00000.png001.png;quaternioncoord(-0.0001;-0.7541;-0.6568;-0.0002);2.1977
Stellarium_test_image_15p00000_0p00000.png001.png;quaternioncoord(-0.4674;0.6334;-0.3146;0.5304);3.7518
Stellarium_test_image_15p00000_30p00000.png001.png;quaternioncoord(0.6044;-0.4361;0.2447;-0.6201);1.3058
Stellarium_test_image_15p00000_60p00000.png001.png;quaternioncoord(0.6754;-0.2255;0.1272;-0.6905);2.3070
Stellarium_test_image_15p00000_90p00000.png001.png;quaternioncoord(-0.6663;-0.0000;-0.0003;0.7457);1.9924
Stellarium_test_image_15p00000_m30p00000.png001.png;quaternioncoord(-0.2371;0.8427;-0.1999;0.4402);6.1671
Stellarium_test_image_15p00000_m60p00000.png001.png;quaternioncoord(0.0583;0.8529;0.4533;0.2524);1.5803
Stellarium_test_image_15p00000_m90p00000.png001.png;quaternioncoord(-0.0001;-0.7546;-0.6561;-0.0002);2.1464
Stellarium_test_image_165p00000_0p00000.png001.png;FAILED;10.4943
Stellarium_test_image_165p00000_30p00000.png001.png;FAILED;8.2187
Stellarium_test_image_165p00000_60p00000.png001.png;quaternioncoord(0.7145;0.1188;-0.2297;-0.6501);1.1551
Stellarium_test_image_165p00000_90p00000.png001.png;quaternioncoord(-0.6670;-0.0000;-0.0003;0.7451);2.0267
Stellarium_test_image_165p00000_m30p00000.png001.png;quaternioncoord(-0.4116;0.6594;0.5616;-0.2836);2.0105
Stellarium_test_image_165p00000_m60p00000.png001.png;quaternioncoord(0.2126;-0.7370;-0.6245;0.1472);2.2077
Stellarium_test_image_165p00000_m90p00000.png001.png;quaternioncoord(-0.0001;-0.7540;-0.6569;-0.0002);1.0697
Stellarium_test_image_180p00000_0p00000.png001.png;FAILED;9.0011
Stellarium_test_image_180p00000_30p00000.png001.png;quaternioncoord(0.4887;-0.4130;-0.2823;0.7148);6.3841
Stellarium_test_image_180p00000_60p00000.png001.png;quaternioncoord(0.5808;0.2069;-0.1553;-0.7719);1.0633
Stellarium_test_image_180p00000_90p00000.png001.png;quaternioncoord(-0.6670;-0.0000;-0.0003;0.7450);2.0306
Stellarium_test_image_180p00000_m30p00000.png001.png;FAILED;13.3318
Stellarium_test_image_180p00000_m60p00000.png001.png;quaternioncoord(0.1736;-0.7163;-0.6482;0.1917);1.4850
Stellarium_test_image_180p00000_m90p00000.png001.png;quaternioncoord(-0.0001;-0.7539;-0.6569;-0.0002);2.2193
Stellarium_test_image_195p00000_0p00000.png001.png;quaternioncoord(0.3149;-0.5301;-0.4683;0.6329);10.4379
Stellarium_test_image_195p00000_30p00000.png001.png;quaternioncoord(-0.2041;0.4390;0.2398;-0.8415);10.9423
Stellarium_test_image_195p00000_60p00000.png001.png;quaternioncoord(0.4680;0.2513;-0.0622;-0.8450);1.1817
Stellarium_test_image_195p00000_90p00000.png001.png;quaternioncoord(-0.6671;-0.0000;-0.0003;0.7450);1.9991
Stellarium_test_image_195p00000_m30p00000.png001.png;quaternioncoord(0.2434;-0.6216;-0.6032;0.4365);1.8818
Stellarium_test_image_195p00000_m60p00000.png001.png;quaternioncoord(-0.1255;0.6944;0.6715;-0.2260);1.4157
Stellarium_test_image_195p00000_m90p00000.png001.png;quaternioncoord(-0.0001;-0.7539;-0.6570;-0.0002);2.1651
Stellarium_test_image_210p00000_0p00000.png001.png;quaternioncoord(-0.1464;0.5260;0.4728;-0.6916);9.0651
Stellarium_test_image_210p00000_30p00000.png001.png;quaternioncoord(-0.0290;0.4245;0.2646;-0.8654);8.3045
Stellarium_test_image_210p00000_60p00000.png001.png;quaternioncoord(0.4184;0.2582;0.0199;-0.8706);2.0232
Stellarium_test_image_210p00000_90p00000.png001.png;quaternioncoord(-0.6672;-0.0000;-0.0003;0.7449);1.9600
Stellarium_test_image_210p00000_m30p00000.png001.png;quaternioncoord(0.1428;-0.5952;-0.6293;0.4790);1.9002
Stellarium_test_image_210p00000_m60p00000.png001.png;quaternioncoord(0.0714;-0.6707;-0.6952;0.2485);1.2101
Stellarium_test_image_210p00000_m90p00000.png001.png;quaternioncoord(-0.0001;-0.7538;-0.6571;-0.0002);2.1513
Stellarium_test_image_225p00000_0p00000.png001.png;quaternioncoord(-0.0283;0.4797;0.5198;-0.7064);1.6026
Stellarium_test_image_225p00000_30p00000.png001.png;quaternioncoord(-0.0973;-0.3911;-0.3119;0.8604);1.0200
Stellarium_test_image_225p00000_60p00000.png001.png;quaternioncoord(0.4121;0.2437;0.0878;-0.8736);1.0138
Stellarium_test_image_225p00000_90p00000.png001.png;quaternioncoord(-0.6673;-0.0000;-0.0003;0.7448);2.0066
Stellarium_test_image_225p00000_m30p00000.png001.png;quaternioncoord(0.0411;-0.5598;-0.6609;0.4981);1.1248
Stellarium_test_image_225p00000_m60p00000.png001.png;quaternioncoord(0.0140;-0.6448;-0.7193;0.2582);1.2858
Stellarium_test_image_225p00000_m90p00000.png001.png;quaternioncoord(-0.0001;-0.7537;-0.6572;-0.0002);2.1504
Stellarium_test_image_240p00000_0p00000.png001.png;quaternioncoord(0.0974;0.4346;0.5580;-0.7002);1.8151
Stellarium_test_image_240p00000_30p00000.png001.png;quaternioncoord(-0.1995;-0.3431;-0.3640;0.8426);2.0259
Stellarium_test_image_240p00000_60p00000.png001.png;quaternioncoord(0.4284;0.2155;0.1438;-0.8657);1.1177
Stellarium_test_image_240p00000_90p00000.png001.png;quaternioncoord(-0.6673;-0.0000;-0.0003;0.7448);2.0007
Stellarium_test_image_240p00000_m30p00000.png001.png;quaternioncoord(-0.0559;-0.5142;-0.6970;0.4966);1.0848
Stellarium_test_image_240p00000_m60p00000.png001.png;quaternioncoord(-0.0436;-0.6167;-0.7435;0.2549);1.3261
Stellarium_test_image_240p00000_m90p00000.png001.png;quaternioncoord(-0.0001;-0.7537;-0.6572;-0.0002);2.2181
Stellarium_test_image_255p00000_0p00000.png001.png;quaternioncoord(0.1944;0.3638;0.6066;-0.6796);1.8677
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

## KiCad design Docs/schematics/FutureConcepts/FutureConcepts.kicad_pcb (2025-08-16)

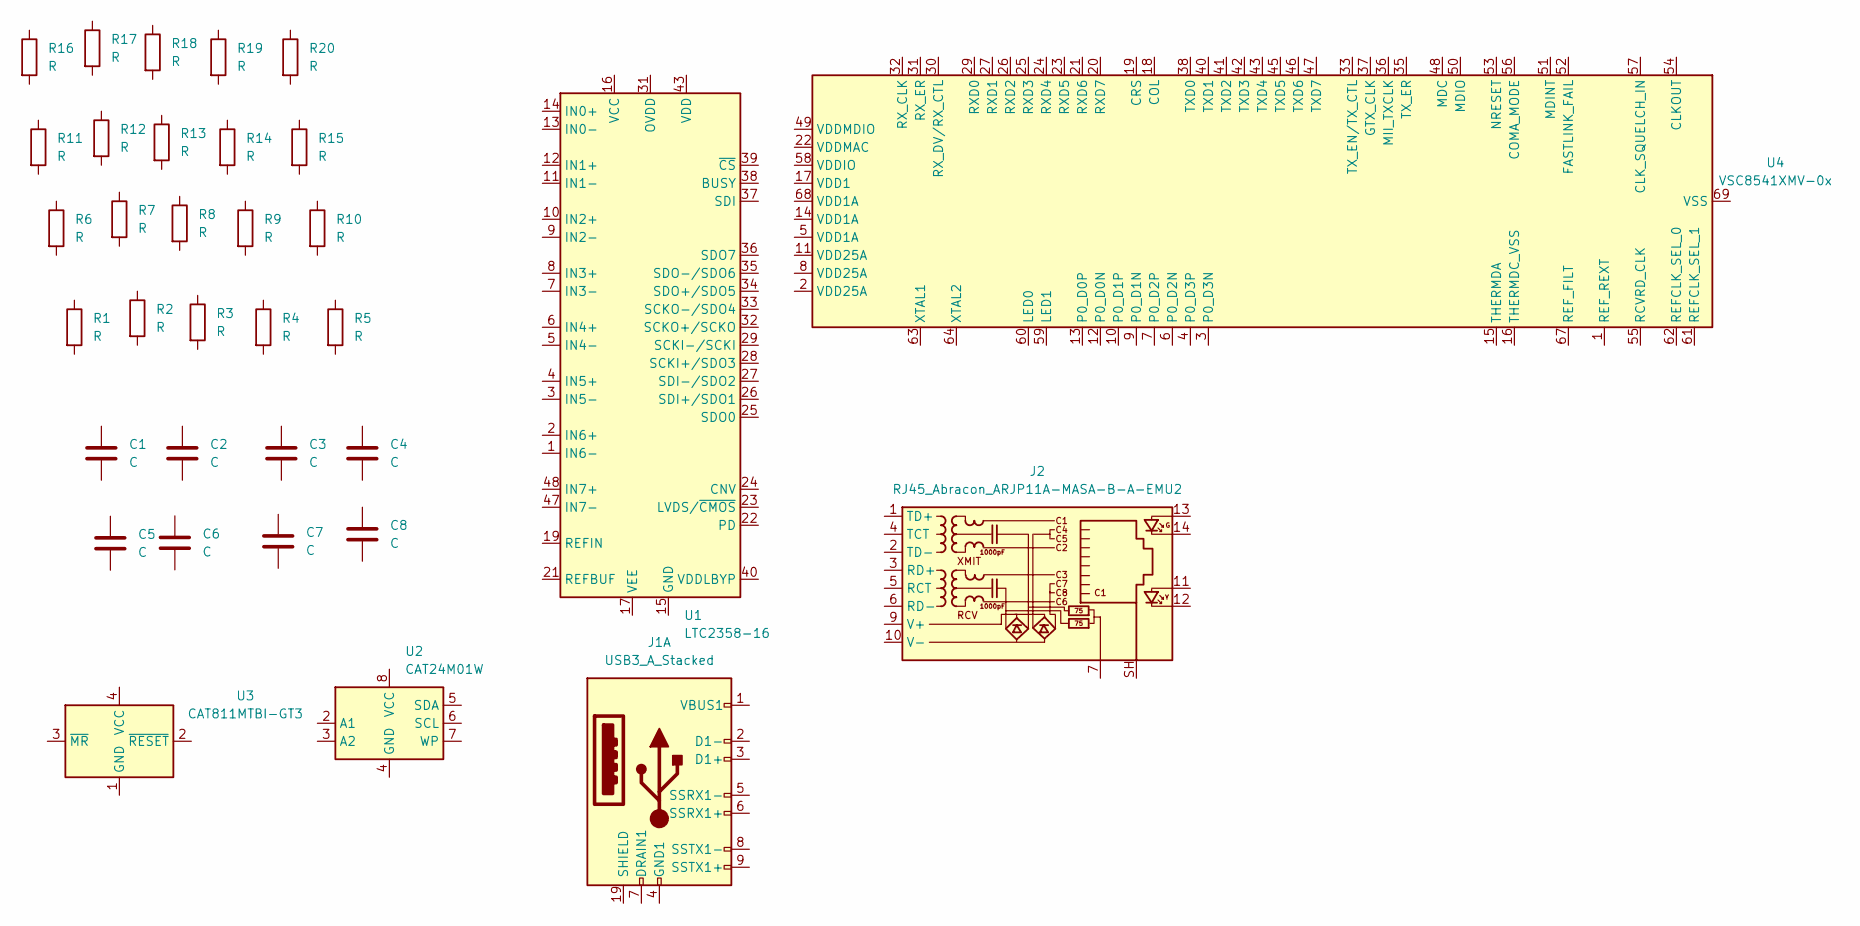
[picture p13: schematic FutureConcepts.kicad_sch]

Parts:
C1, C2, C3, C4, C5, C6, C7, C8: C; C_Elec_6.3x5.4
J1: USB3_A_Stacked; USB3_A_Molex_48406-0001_Horizontal_Stacked
J2: RJ45_Abracon_ARJP11A-MASA-B-A-EMU2; RJ45_Abracon_ARJP11A-MA_Horizontal
R1, R2, R3, R4, R5, R6, R7, R8, R9, R10, R11, R12, R13, R14, R15, R16, R17, R18, R19, R20: R; R_2010_5025Metric_Pad1.40x2.65mm_HandSolder
U1: LTC2358-16; LQFP-48_7x7mm_P0.5mm
U2: CAT24M01W; SOIC-8_3.9x4.9mm_P1.27mm
U3: CAT811MTBI-GT3; SOT-143
U4: VSC8541XMV-0x; QFN-68-1EP_8x8mm_P0.4mm_EP5.2x5.2mm

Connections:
unnamed: U1.15 (GND), U1.18 (GND), U1.20 (GND), U1.30 (GND), U1.41 (GND), U1.44 (GND), U1.46 (GND)
unnamed: U1.42 (VDD), U1.43 (VDD)
unnamed: U1.17 (VEE), U1.45 (VEE)
unnamed: U4.17 (VDD1), U4.34 (VDD1)
unnamed: U4.22 (VDDMAC), U4.28 (VDDMAC), U4.39 (VDDMAC), U4.44 (VDDMAC)

Board: 2 copper layers, 35 parts (0 on the bottom side), 5 nets, no tracks yet.

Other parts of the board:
Module1: ComputeModule5-CM5; Raspberry-Pi-5-Compute-Module

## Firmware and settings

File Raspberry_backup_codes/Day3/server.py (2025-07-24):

from flask import Flask, render_template, Response, jsonify
from picamera2 import Picamera2
import cv2
import time
import board
import busio
import adafruit_bno055

# --- Flask App Setup ---
from imutils.video import VideoStream

app = Flask(__name__)

# --- Camera Setup ---
picam2 = Picamera2()
picam2.configure(picam2.create_video_configuration(main={"size": (640, 480)}))
picam2.set_controls({
    "FrameDurationLimits": (33333, 33333),  # 30 fps
    "ExposureTime": 10000,  # 10 ms
    "AnalogueGain": 1.0,
    "AwbEnable": False,
    "AeEnable": False,
    "AwbMode": 0,
})
picam2.start()
time.sleep(1)  # Let camera warm up

# --- BNO055 Sensor Setup ---
i2c = busio.I2C(board.SCL, board.SDA)
sensor = adafruit_bno055.BNO055_I2C(i2c)
def return_data():
    return sensor.euler

time.sleep(1)
sensor.mode = adafruit_bno055.CONFIG_MODE
time.sleep(0.5)
sensor.mode = adafruit_bno055.NDOF_MODE
time.sleep(0.5)
print("BNO055 Sensor Initialized.")


cal = sensor.calibration_status
sys, gyro, accel, mag = cal
print(f"Calibration Status - Sys: {sys}, Gyro: {gyro}, Accel: {accel}, Mag: {mag}")

# --- Rotation Data (Global Variable) ---
rotation_data = {"euler": None, "quaternion": None, "temperature": None}

# --- Frame Generator ---
def gen_frames():
    global rotation_data
    while True:
        frame = picam2.capture_array()
        frame = cv2.cvtColor(frame, cv2.COLOR_RGB2BGR)
        frame = cv2.flip(frame, -1)

        # --- Read Sensor Data ---
        try:
            euler = sensor.euler
            quat = sensor.quaternion
            temp = sensor.temperature

            rotation_data = {
                "euler": euler,
                "quaternion": quat,
                "temperature": temp
            }

            # Optional: Draw Euler Angles on Frame
            if euler:
                text = f"Euler: {euler}"
                cv2.putText(frame, text, (10, 30), cv2.FONT_HERSHEY_SIMPLEX, 0.6, (0, 255, 0), 2)
        except Exception as e:
            print(f"Sensor error: {e}")

        # Encode frame
        _, buffer = cv2.imencode('.jpg', frame)
        frame_bytes = buffer.tobytes()
        yield (b'--frame\r\n'
               b'Content-Type: image/jpeg\r\n\r\n' + frame_bytes + b'\r\n')

# --- Flask Routes ---
@app.route('/')
def index():
    return '''
    <html>
        <head><title>Raspberry Pi Camera</title></head>
        <body>
            <h1>Live Camera Stream</h1>
           <div style="
  display: flex;
  flex-wrap: wrap;">
            <img style="" src="/video_feed">
            <h2>Rotation Data</h2>
            <pre style="" id="rotation-data">Loading...</pre>
           </div>
             <button onclick="calibrateGyro()">Click Me</button>
             <p id="status-msg"></p>
            <script>
                setInterval(async () => {
                    const res = await fetch("/rotation");
                    const data = await res.json();
                    document.getElementById("rotation-data").textContent = JSON.stringify(data, null, 2);
                }, 300);
                async function calibrateGyro() {
                    const res = await fetch("/calibrate", {
                        method: "POST"
                    });
                    const data = await res.json();
                    document.getElementById("status-msg").textContent = data.message;
                }
            </script>
        </body>
    </html>
    '''

@app.route('/video_feed')
def video_feed():
    return Response(gen_frames(), mimetype='multipart/x-mixed-replace; boundary=frame')

@app.route('/rotation')
def rotation():
    return jsonify(rotation_data)

@app.route('/calibrate', methods=['POST'])
def calibrate():
    print("Button was clicked!")
    return jsonify({"status": "success", "message": "Calibration is on {}!".format(return_data())})



# --- Main ---
if __name__ == '__main__':
    app.run(host='0.0.0.0', port=5000)

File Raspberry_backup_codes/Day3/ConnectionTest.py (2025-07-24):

import time
import board
import busio
import adafruit_bno055

i2c = busio.I2C(board.SCL, board.SDA)
sensor = adafruit_bno055.BNO055_I2C(i2c)

# Give sensor time to initialize
time.sleep(1)

# Optionally reset mode
sensor.mode = adafruit_bno055.CONFIG_MODE
time.sleep(0.5)
sensor.mode = adafruit_bno055.NDOF_MODE
time.sleep(0.5)

print("BNO055 Sensor Initialization Complete\n")

while True:
    try:
        euler = sensor.euler
        quat = sensor.quaternion
        temp = sensor.temperature

        print(f"Euler: {euler}")
        print(f"Quaternion: {quat}")
        print(f"Temperature: {temp} °C")
        print("--------------------")
        time.sleep(0.15)
    except Exception as e:
        print(f"Error reading sensor: {e}")
        time.sleep(2)

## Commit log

2025-07-24 ☆ star_coords_to_unit_vector and angular_distances functions
    - star_coords_to_unit_vector:
    The function takes the parameters of the camera (center coordinates, focal length) and an array of star coordinates in the image. I then returns a list of unit vectors for each star
    - angular_distances:
    The function takes a list of unit vectors and calculates the angular distances between each pair of stars.
    Returns an array of all of them
    - Also I deleted the two previous digital twins since they were AI and stuff
2025-07-25 ☆ some refactoring
2025-07-25 ☆ hypothesises dict construction
    trying to make a graph-like structure in the form of a dict
    Then I'll attempt some sort of graph traversal algorithm + maybe voting algorithm to get final mapping of the stars
    - load_catalog_angular_distances(): query to db to get all pairs of angular distances within a certain tolerance. Probably going to change it to a k-vector
    - display_star_detections(): moved the displaying code to a separate function
    - within_bounds(): calculate min max based on tolerance of the angular distance arg
    - load_hypothesies: returns a dict where the key is the index of the star in our image and the value is a list of all the possible hip id's it could be
    [main.py]
2025-07-25 Hardware backup!
    [SatDownbase.FCStd]
2025-07-25 added diagram
    [SatDownbase.FCStd]
2025-07-26 ☆ Readme update
2025-07-26 ☆ Readme update + repo structure
2025-07-26 ☆ Another Readme update
2025-07-26 Create CAD image.png
2025-07-26 ☆ Refactoring
    - catalog_angular_distances(): returns a dict where the key is a tuple of a pair of the stars in our image and the value is a dict of all candidate pairs in the database and their angular distance
    -image_processing folder: testing other algorithms to get more correct pixel coordinates
    [main.py]
2025-07-29 ☆ Retrying push
    I don't know why my last two commits didn't change main.py I guess it wasn't selected. Happy my computer didn't crash out
    [main.py]
2025-07-30 update main with new image filter
2025-07-30 ☆ Final mappin (added subgraph scoring)
    - So turns out geometric hashing is still way to slow even when the
    - DFS(): now it adds all possible assignments it's gone through even if they aren't full to the solutions array
    - score_solution(): given a solution the function returns a tuple of the solution and it's score. The score is calculated based on the angular distance offset between image and catalog pair angular distances. I also account for circular warparound. I value solutions with a higher amount of stars maps. Overall the lower the score the better the match
    - load_solution_scoring(): returns an array of tuple where each element is the solution and it's score
    !!! It's still a bi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
    [main.py]
2025-07-30 ☆ QUEST implementation
    !!! Need to add weights for reliability of each mapping of star to hip, so that outliers don't affect our end attitude as much
    - here I assume that all star assignments can be equally trusted
    - also need to optimize dfs
2025-07-30 ui software; current working firmware; research of hardware backup systems; moved old files;
2025-07-31 ☆ Refactoring
    - tried to sort my hypothesises before DFS to apply a minimum remaining values heuristic, doesn't really make that big of a change though
    - image processing refactoring (Ivo, don't use that much AI, please)
    [main.py]
2025-07-31 txt file for UART progress and code in case LOST
2025-07-31 ☆ Lost in space 1st draft documentation
2025-07-31 initial UART done
2025-08-04 ☆ unit vector changes
    - Refactoring + Viktor Danchev style comments
2025-08-04 ☆ Angular distance calculation optimization
    - using matrix multiplication instead of for loops. Time complexity is still O(N^2), but constant factors are reduced. Numpy uses BLAS C interfaces => faster
2025-08-04 ☆ catalog extraction + hypotheses construction
    - query sent to the database only once for the angular distances. Afterwards filtering done in python
2025-08-04 ☆ improvements to DFS logic
    - I'm scared that someone's gonna think the comments are because the code is copy-pasted AI when I write them manually 'cause I like how Viktor Danchev writes his code
2025-08-04 ☆ New image processing module
2025-08-04 ☆ Solution scoring refactoring
2025-08-05 ☆ Weighted sum matrix refactoring + explanation comments
2025-08-05 ☆ Digital twin testing images
2025-08-05 new schematics; logo uploaded; some documentation on data; some concept diagrams
    [Hardware.kicad_pcb, Hardware.kicad_sch]
2025-08-06 ☆ New image processing (refactored) + new test images
    The image processing code is not my own it's Ivo's he just told me to refactor it
2025-08-07 ☆ Hypothesis construction optimization + new testing images
2025-08-07 ☆ Added inverse_rotate_vectors function
2025-08-07 ☆ Add reprojecting catalog vectors to image plane logic
2025-08-07 ☆ Correcting quaternion logic - add calculate_error and calculate_weights function. Manually correcting original quaternion once
    [main.py]
2025-08-07 first working demo; some research; website fixes
    [Flare.py, FlaskServer.py, IMU.py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]
2025-08-09 ☆ testing images
2025-08-09 ☆ using subpixel accuracy for lost-in-space
2025-08-10 current working code; quatenrion visualzaiton in interface; bit docs
2025-08-10 fixed main (my bad)
    [main.py]
2025-08-11 ☆ baffle block simulation images
2025-08-11 ☆ Fixing docstrings
    I know this is pointless, don't blame me guys
    [main.py]
2025-08-11 ☆ fixed image path
    [main.py]
2025-08-11 ☆ Fine-tuning of parameters - lost-in-space big speed-up
2025-08-12 added potential hash dictionary with voting system for filtering the potential candidates before the DFS
2025-08-12 ☆ tracking functionality first version + testing images
2025-08-13 ☆ testing and refactoring tracking
2025-08-13 ☆ Function to refine quaternion before returning is from lost-in-space
2025-08-13 ☆ Rotational angle between quaternions function
2025-08-13 ☆ testing new error rates and weights functions with radians + rotational angle between quaternions fixed
    [main.py]
2025-08-14 ☆ Lost-in-Space using testing image if None provided + new testing images
2025-08-15 ☆ Quaternion refinement pipeline upgrade
2025-08-15 ☆ Tracking and unit vector conversion optimisation with vectorised operations
2025-08-15 ☆ Create hash functionality added to main digital twin + generated pickle file
2025-08-15 ☆ Added hypotheses generation for DFS based on catalog hash functions
2025-08-15 ☆ DFS with new hypotheses + tracking changes + testing images
2025-08-16 presentation future concept; beginning of tests ( stashed for testing integration rn)
    [FutureConcepts.kicad_pcb, FutureConcepts.kicad_sch]
2025-08-16 ☆ Added planetary exclusion iteration
2025-08-16 ☆ New file structure + star tracker related classes
    !!! Not tested yet !!!
    + haven't written the __init__ files
2025-08-16 ☆ lost-in-space testing
    !!! have to fix dir of stars_identified.png
2025-08-17 ☆ Fixed identified stars image output dir
2025-08-17 ☆ Tracking fix parameters passed. Doesn't break
    [main.py]
2025-08-17 added sun filter to the thanos gauntlet
2025-08-17 ☆ Hungarian algorithm matching instead of greedy first smallest distance
2025-08-18 ☆ Error handling for unit vectors and angular distances + types
    [main.py]
2025-08-18 ☆ Hypotheses building error handling + type hints
    [main.py]
2025-08-18 ☆ Fixed tracking solution indexation and added new returns to track function + DFS error handling + new testing images
    [main.py]
2025-08-18 rework batch validation
    [results.csv]
2025-08-18 ☆ Modes + loop through multiple images with tracking
2025-08-19 ☆ More testing of tracking
2025-08-20 ☆ testing images + clean version update
2025-08-21 ☆ README update + testing images
2025-08-26 backup of source code; final developer UI
    [model.stl, old_model.stl]
